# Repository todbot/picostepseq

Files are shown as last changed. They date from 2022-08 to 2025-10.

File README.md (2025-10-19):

# PicoStepSeq

PicoStepSeq is an 8-step MIDI sequencer using a Raspberry Pi Pico, an I2C SSD1306 OLED display, a rotary encoder. and 8 "Step Switches".  It outputs via USB MIDI and Serial MIDI via TRS-A 3.5mm.

It is designed as a potential DIY kit for people with beginner-level soldering skills
Part count is minimal, with all parts are through-hole, except for the two MIDI jacks,
which are easily solderable by hand.

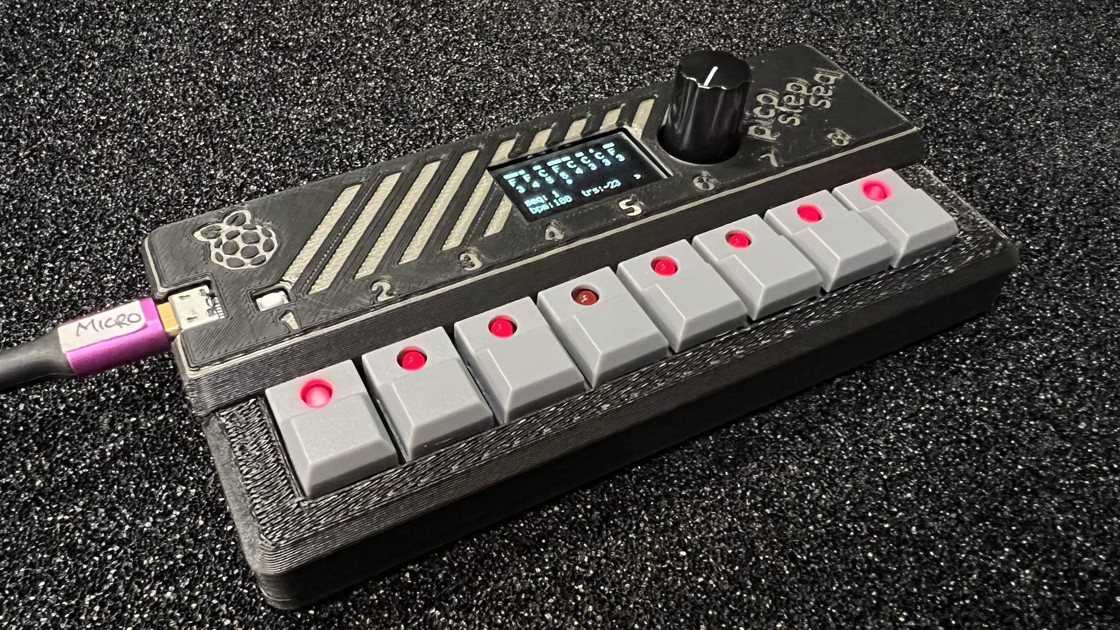
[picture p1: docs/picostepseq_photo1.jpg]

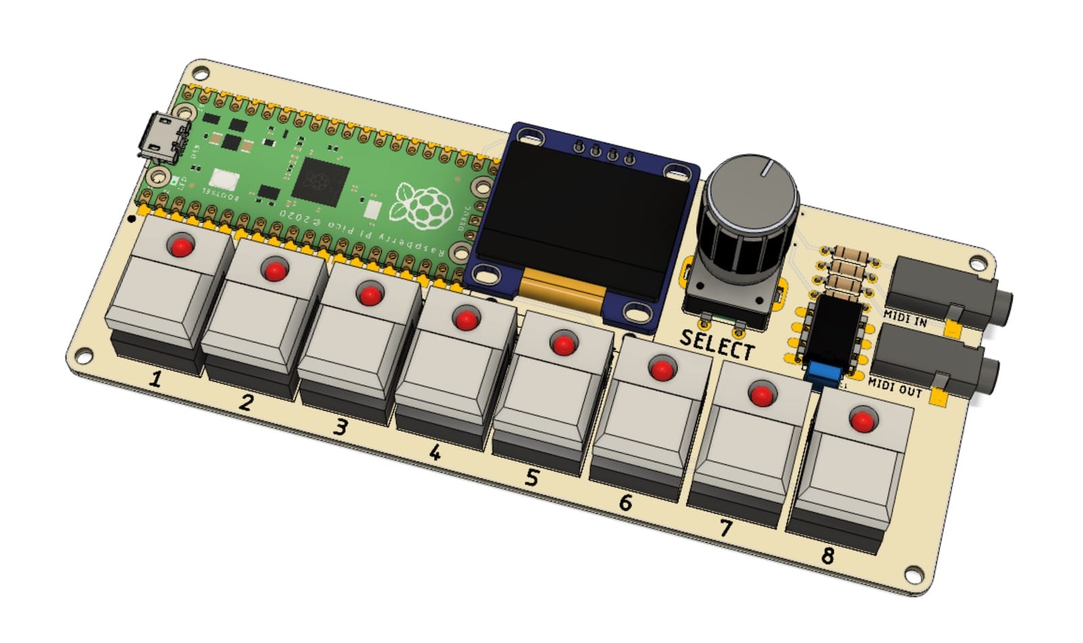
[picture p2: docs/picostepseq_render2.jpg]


## Demo videos

https://user-images.githubusercontent.com/274093/185005269-afb4c3f7-0ca1-40c8-a17d-6e4756943d87.mov

https://user-images.githubusercontent.com/274093/196536711-abd25514-53b9-4710-8ff6-1fa3559f0028.mp4

Also featured in [MagPi Magazine #123](https://magpi.raspberrypi.com/articles/picostepseq-rp2040-music-maker), and [in print too](https://magpi.raspberrypi.com/issues/123)!

## How to use

In use, PicoStepSeq has two states: Play and Pause.
It is designed so you never have to stop playing to edit and save/load a sequence.
It has 8 sequence slots that can be edited and are persistently saved to flash.

While Playing, the actions are:

- **Pause** -- Tap encoder button
- **Transpose sequence up/down** -- Turn encoder knob
- **Change tempo BPM** -- Push + turn encoder knob
- **Mute / Unmute steps** -- Tap corresponding step key
- **Change step's pitch** -- Hold step key, turn encoder knob
- **Change step's gate** -- Hold step key, push + turn encoder knob
- **Load sequence** -- Push encoder, tap step key 1-8, release encoder
- **Save sequence** -- Push encoder, hold step key 1-8 for 2 secs, release encoder

When Paused, the actions are:
- **Play** -- Tap encoder button
- **Play notes** -- tap corresponding step key to play its pitch
- **Change step's pitch** -- Hold step key, turn encoder knob

Sequence Save & Load:
- On startup, `saved_sequences.json` is read from disk and loaded into the 8 sequence slots
- Upon transitioning from Play to Pause, all 8 sequences will be written to disk as `saved_sequences.json`

### Step Keys

The 8 "step keys" have an LED that indicate current mute/unmute status and which step is currently being played.
Tap on a step key to mute/unmute it. Hold a key and turn the encoder knob to change the pitch of that step.

### Rotary Encoder

Turning the encoder adjusts the transpose amount of the playing sequence.  Push + turning adjusts the tempo.

### Display

PicoStepSeq can be used without really looking at the display (which is good because the display is very small).
The display is hopefully clear. It's divided into the top section showing 8 notes with gate info and the bottom section showing which sequence, current BPM & transpose, and if the sequencer is in play/pause mode.

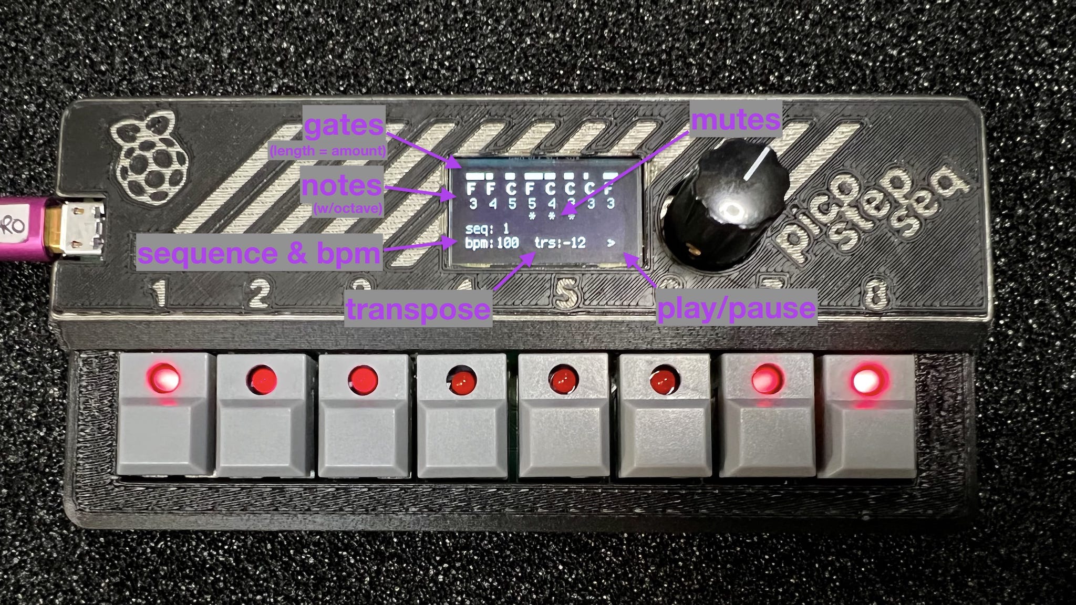
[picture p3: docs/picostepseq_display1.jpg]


### MIDI

PicoStepSeq outputs both USB MIDI and Serial MIDI.

There is preliminary support for syncing to MIDI Clock.

## Building

The schematic and PCB design is in the `hardware` directory.

An [OSHPark project](https://oshpark.com/shared_projects/vPWjBrmO) of the PCBs is ready to go.

[Build guide to come!]

### Enclosure

A 3d-printable enclosure is [available on Printables](https://www.printables.com/model/260860-picostepseq-midi-step-sequencer-w-raspberry-pi-pic)

The current enclosure is designed for the case where sockets are used for both the Pico and the OLED display.
This is so either can be removed for other uses, so you don't have to sacrifice a Pico if you want to try this out.

### Installing Firmware (CircuitPython)

#### Arduino version:

Probalby the easiest way to get PicoStepSeq running is to install the precompiled Arduino UF2
version in the [Releases](https://github.com/todbot/picostepseq/releases) section.

The Arduino firmware lives in `arduino/picostepseq`.
To compile the Arduino firmware, see the top of the `picostepseq.ino` file.

#### CircuitPython version:

To install the CircuitPython version:

The firmware lives in the `circuitpython/picostepseq` directory.

1. Copy all files in the `circuitpython/picostepseq` directory to the CIRCUITPY disk.

   If using a Mac terminal, you can do:
   ```sh
   cd picostepseq/circuitpython/picostepseq
   cp -rX * /Volumes/CIRCUITPY
   ```

2. Install the CircuitPython libraries `adafruit_displayio_ssd1306` and `adafruit_display_text`

   You can use the `circup` tool in Terminal for this:

   ```sh
   circup install adafruit_displayio_ssd1306 adafruit_display_text
   ```

   If you do not have `circup`, then you will need to copy the following files/dirs from the
   [Adafruit_CircuitPython_Bundle 8.x](https://circuitpython.org/libraries):
   ```
   adafruit_bitmap_font/
   adafruit_display_text/
   adafruit_displayio_ssd1306.mpy
   ```

3. Reset the board and the sequencer should come up!

   (The reset is important so that `boot.py` is run, which allows you to save sequences)

### Installing the Firmware (Arduino)

The Arduino version is a bit more tricky to get going. See the top of the `picostepseq.ino` file for details.

## Bill of Materials

Here is a [Digikey cart with most parts](https://www.digikey.com/short/8qh7p87z).

Links also included below for major parts

For basic USB MIDI functionality:

- 1 - "picostepseq" PCB ([OSHpark](https://oshpark.com/shared_projects/vPWjBrmO), also see "hardware" directory for gerbers)
- 1 - Raspberry Pi Pico ([Adafruit](https://www.adafruit.com/product/4864), [Digikey](https://www.digikey.com/en/products/detail/raspberry-pi/SC0915/13624793))
- 1 - 0.96" I2C OLED SSD1306 128x64 display ([Amazon](https://amzn.to/3K1ZAoo))
  - w/ pins in order GND, VCC, SCL, SDA; some have GND & VCC swapped
- 1 - EC11 style rotary encoder w/ switch ([Digikey](https://www.digikey.com/en/products/detail/bourns-inc/PEC11R-4215F-S0024/4499665), [Adafruit](https://www.adafruit.com/product/377)]
- 8 - "step switch" w/ built-in LED ([Adafruit](https://www.adafruit.com/product/5519)]
- 8 - resistor 1k (R1-R8, 500 ohm also works) ([Digikey](https://www.digikey.com/en/products/detail/stackpole-electronics-inc/CF18JT1K00/1741612), [Adafruit](https://www.adafruit.com/product/4294)]
- 1 - encoder knob ("Davies 1900" style works well, [Adafruit](https://www.adafruit.com/product/5541))

For both USB + Serial MIDI, add:

- 2 - 3.5mm TRS jack, SJ-3523-SMT-TR (J1,J2)
([Digikey](https://www.digikey.com/en/products/detail/cui-devices/SJ-3523-SMT-TR/281297))
- 1 - 6N138 optoisolator (U2) ([Digikey](https://www.digikey.com/en/products/detail/liteon/6N138/1969179))
- 1 - 100n capacitor (C1) ([Digikey](https://www.digikey.com/en/products/detail/vishay-beyschlag-draloric-bc-components/K104K15X7RF5TL2/286538), [Adafruit](https://www.adafruit.com/product/753))
- 1 - resistor 10 ohm (R1)
- 1 - resistor 30 ohm (R2) (47 ohm also works)
- 1 - resistor 220 ohm (R3)
- 1 - resistor 4.7k ohm (R4)

And if you've not used ["TRS MIDI"](https://minimidi.world/#types) and have normal 5-pin DIN MIDI jacks
on your gear, you'll need a few:
- Type A" MIDI adapter ([PerfectCircuit](https://www.perfectcircuit.com/make-noise-0-coast-midi-cable.html) or [Amazon](https://amzn.to/3Tb6DiU))

You can attach the Pico & the OLED display how you like, but if using the 3d-printable "picostepseq_headers" case, you will also need:

- 2 - 20-pin header socket ([Digikey](https://www.digikey.com/en/products/detail/sullins-connector-solutions/PPPC201LFBN-RC/810192), [Adafruit](https://www.adafruit.com/product/5583))
- 2 - 20-pin header pins ([Digikey](https://www.digikey.com/en/products/detail/adam-tech/PH1-20-UA/9830398), [Adafruit ](https://www.adafruit.com/product/392))
- 1 - 4-pin female (same as above, break off 4-pin chunk)

## Firmware Design (CircuitPython)

Timing in CircuitPython is all over the place and there's no periodic timer support (like `Timer` in MicroPython).
So, in order to minimize timing jitter due to I2C `displayio` transactions, the UI & display update code
is designed so only the minimal amount of information is changed on the display in one iteration of the main
UI loop. This is most noticable when loading a new sequence: the entire sequence is revealed only after a full
loop.

The sequencer "beat scheduler" also tries to account for the variation in CircuitPython timing by
measuring an "error" on the delta_t between beats and applies that to the next beat

[More to come!]

Thanks to [Winterbloom](https://github.com/wntrblm) and [@theacodes](https://github.com/theacodes) for the awesome
[SmolMIDI library](https://github.com/wntrblm/Winterbloom_SmolMIDI) for efficient MIDI parsing.
(and for [really cool Eurorack synthesizer devices](https://winterbloom.com/shop))

**Note:** If you have an [Adafruit MacroPad RP2040](https://www.adafruit.com/product/5128),
you can experiment with the sequencer without building any hardware! The code will auto-detect
if it's running on a MacroPad. Rotate the MacroPad so the display is on the left,
then the sequencer keys are arranged as two rows of four.

Here's a demo video of an early dev version of the sequencer running on the MacroPad:

https://user-images.githubusercontent.com/274093/196534059-c9460560-1983-42a2-818f-853e90acd9bf.mp4

## PCB layout

This is the original version that has a typo on the MIDI jacks.

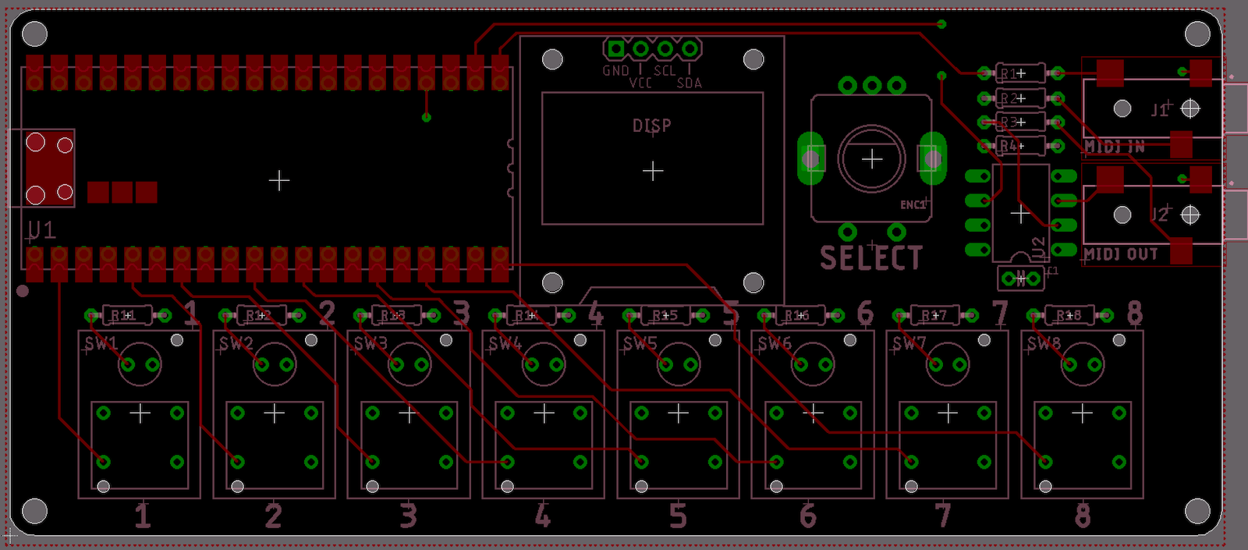
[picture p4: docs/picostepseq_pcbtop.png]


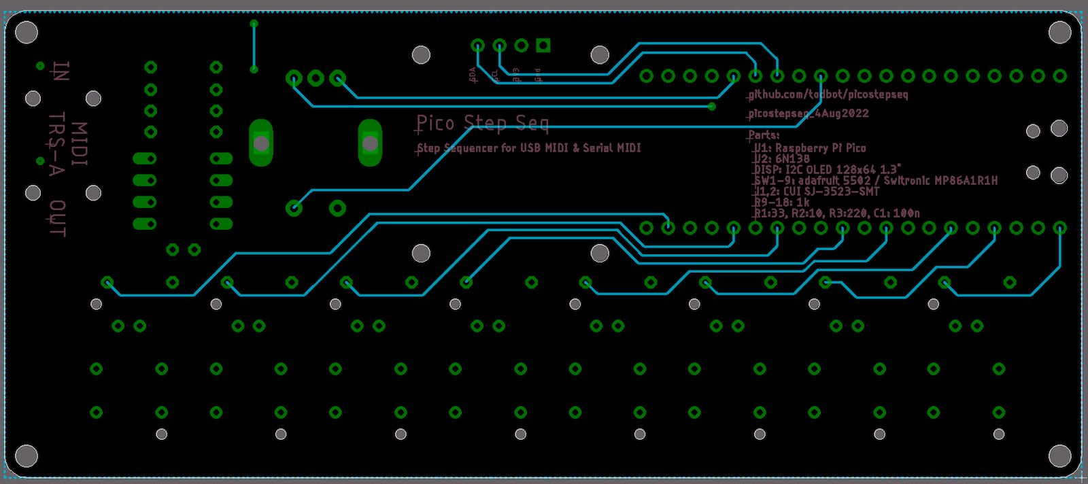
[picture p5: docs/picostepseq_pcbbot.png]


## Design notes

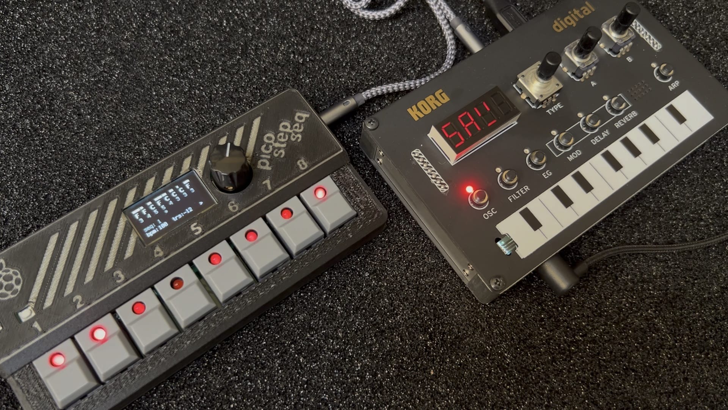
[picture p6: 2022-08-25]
docs/picostepseq_korg1.jpg

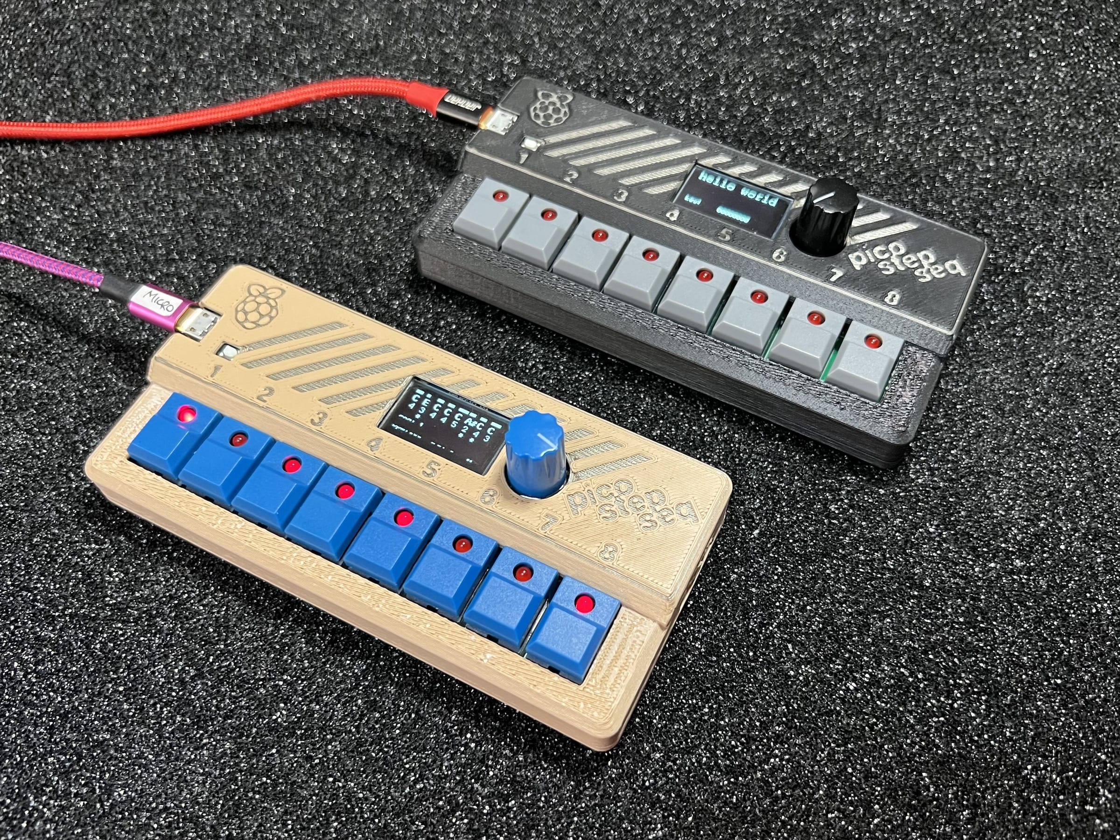
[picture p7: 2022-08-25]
docs/picostepseq_multicolor.jpg

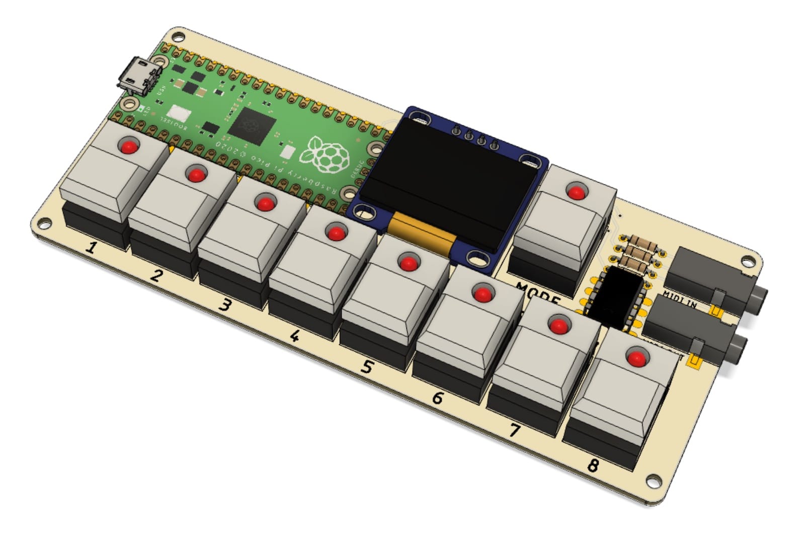
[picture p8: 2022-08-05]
docs/picostepseq_render1.jpg

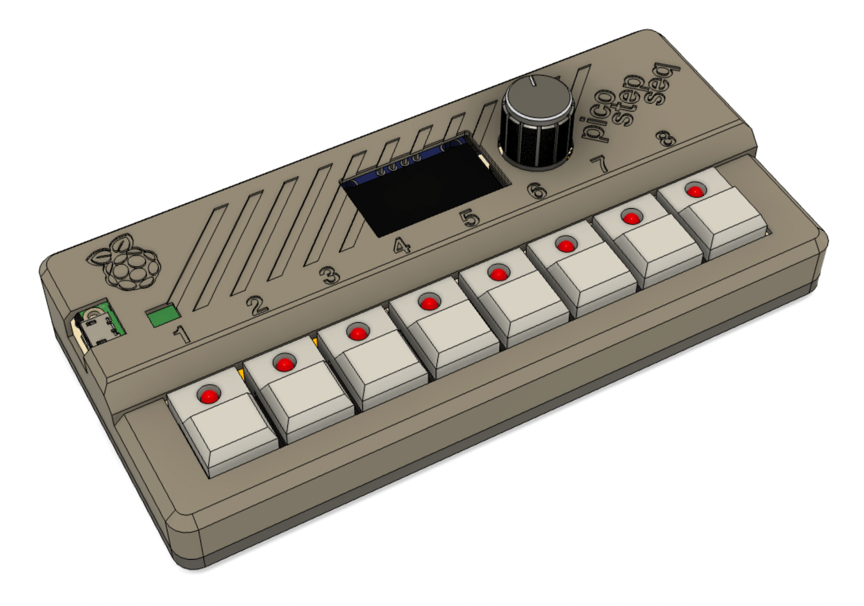
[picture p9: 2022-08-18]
case/picostepseq_case_render1.png

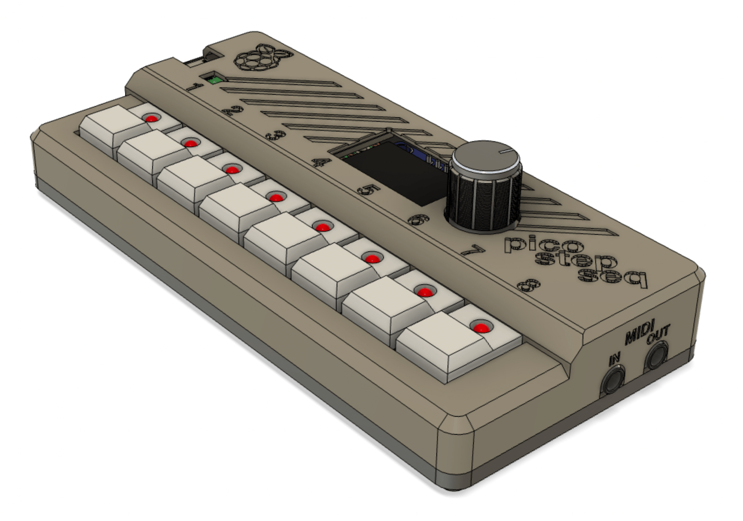
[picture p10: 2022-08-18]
case/picostepseq_case_render2.png

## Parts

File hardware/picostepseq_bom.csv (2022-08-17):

Qty | Value | Device | Package | Parts | Description | CUI_PURCHASE_URL | DESCRIPTION | DIGI-KEY_PART_NUMBER | MF | MP | MPN | OC_FARNELL | OC_NEWARK | PACKAGE | POPULARITY | PURCHASE-URL | SPICEPREFIX
1 |  | C-EU025-025X050 | C025-025X050 | C1 | CAPACITOR, European symbol |  |  |  |  |  |  |  |  |  | 65 |  | C
1 |  | RASPBERRY_PICO-NO_DEBUG | PICO-PKG-NO_DEBUG | U1
1 | 10 | R-EU_0204/7 | 0204/7 | R1 | RESISTOR, European symbol |  |  |  |  |  |  |  |  |  | 79 |  | R
8 | 1k | R-EU_0204/7 | 0204/7 | R11, R12, R13, R14, R15, R16, R17, R18 | RESISTOR, European symbol |  |  |  |  |  |  |  |  |  | 79 |  | R
1 | 220 | R-EU_0204/7 | 0204/7 | R3 | RESISTOR, European symbol |  |  |  |  |  |  |  |  |  | 79 |  | R
1 | 33 | R-EU_0204/7 | 0204/7 | R2 | RESISTOR, European symbol |  |  |  |  |  |  |  |  |  | 79 |  | R
1 | 4.70k | R-EU_0204/7 | 0204/7 | R4 | RESISTOR, European symbol |  |  |  |  |  |  |  |  |  | 79 |  | R
1 | 6N137 | 6N137 | DIL08 | U2 | MOTOROLA OPTO COUPLER |  |  |  |  |  | 6N137 | 1328376 | 52M1895 |  | 2
1 | DISPLAY-OLED-128X64-I2C | DISPLAY-OLED-128X64-I2C | DISPLAY-OLED-128X64-I2C | DISP | 128x64 Dot Matrix OLED Module based on SSD1306 chip
8 | LED_SWITCHSTEP | LED_SWITCHSTEP | LED_SWITCH_STEP | SW1, SW2, SW3, SW4, SW5, SW6, SW7, SW8 | Step switch with LED, like on old drum machines
1 | PEC11 | ENCODER_PLUS_SWITCH_BOURNS_PEC11 | PEC11+SWITCH | ENC1 | Rotary Encoder with Built-In Switch
2 | SJ-3523-SMT | SJ-3523-SMT | CUI_SJ-3523-SMT | J1, J2 | Audio Jack Connector 3.5 mm Low Profile Surface Mount Stereo Jack, 3 Pin Right-Angle | https://www.cuidevices.com/product/interconnect/connectors/audio-connectors/jacks/sj-352x-smt-series | 3.5 mm, Stereo, Right Angle, Surface Mount (SMT), 3 Conductors, 0~1 Internal Switches, Audio Jack Connector | CP-3523SJCT-ND | CUI Devices | SJ-3523-SMT-TR |  |  |  | None |  | https://pricing.snapeda.com/search/part/SJ-3523-SMT-TR/?ref=eda

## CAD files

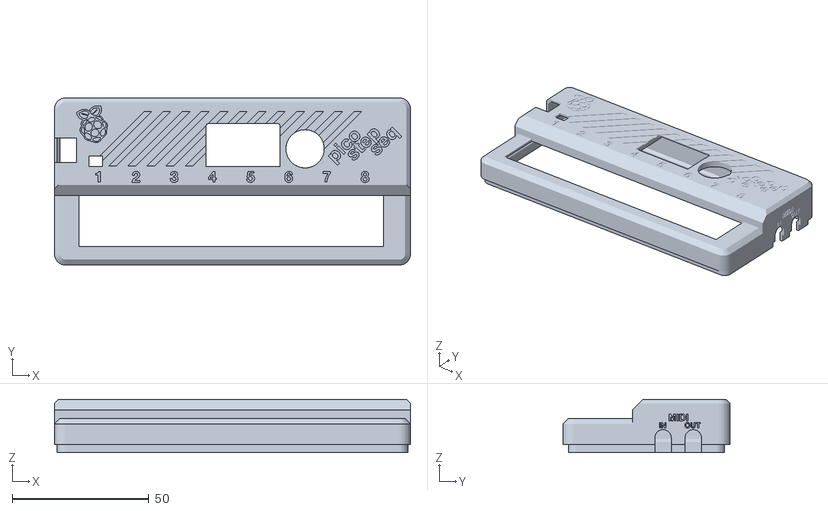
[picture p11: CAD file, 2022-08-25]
case/picostepseq_case_top.stl
130.3 x 61.2 x 19.6

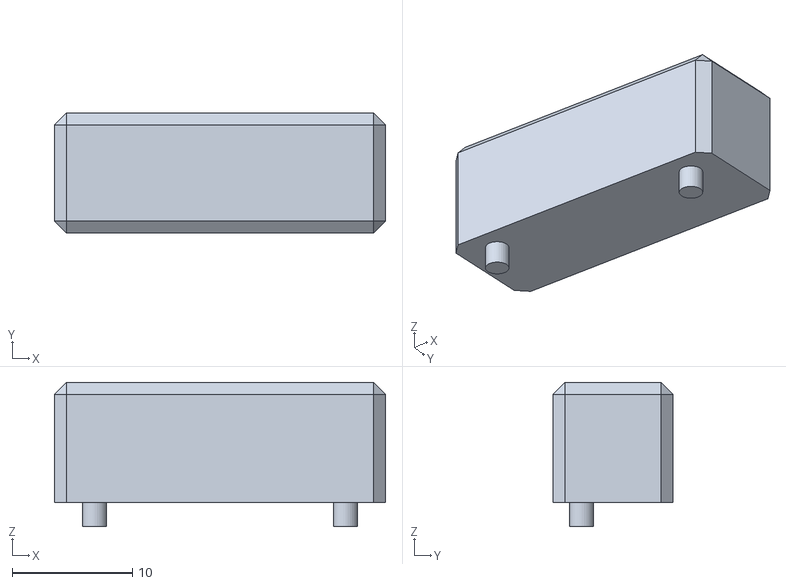
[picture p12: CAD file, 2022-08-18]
case/picostepseq_case_oledspacer.stl
27.5 x 10.0 x 12.0

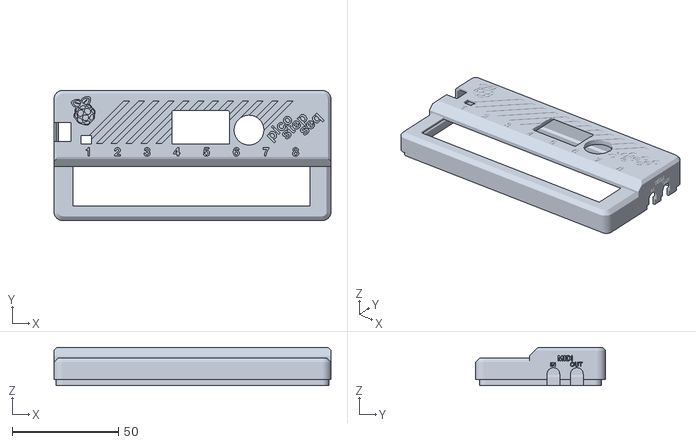
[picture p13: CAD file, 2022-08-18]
case/picostepseq_case_top_short.stl
130.3 x 61.2 x 18.1

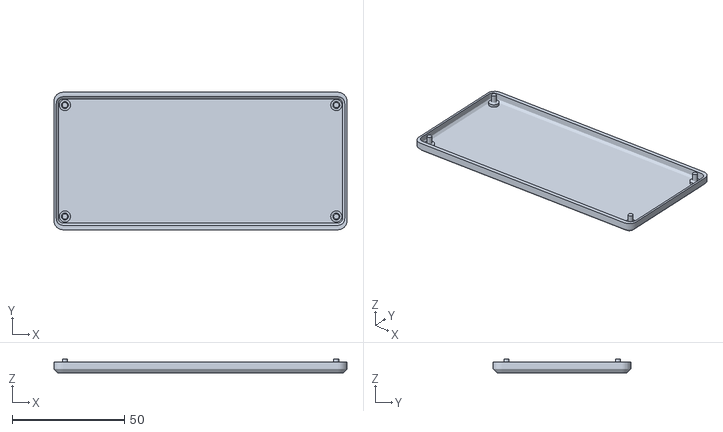
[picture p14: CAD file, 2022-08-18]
case/picostepseq_case_bottom.stl
130.3 x 61.2 x 6.30

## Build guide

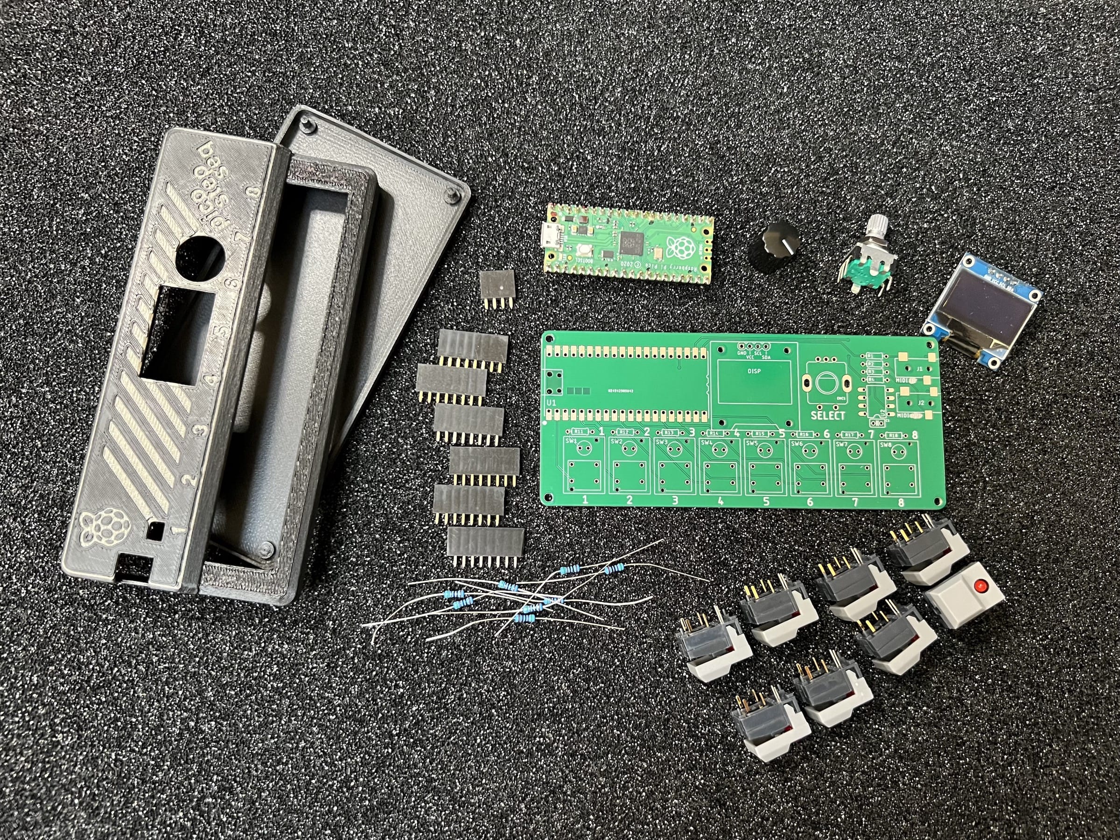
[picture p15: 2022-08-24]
docs/picostepseq_assembly1.jpg

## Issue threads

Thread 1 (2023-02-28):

Circuit Python libraries needed

gmeader, 2023-02-28:
I got my board assembled and it works.
The following Circuit Python Libraries are needed in the lib folder to successfully run both the test/hardware_test_code.py and the main picostepseq/code.py:

- adafruit_bitmap_font
- adafruit_display_text
- adafruit_debouncer.mpy
- adafruit_displayio_ssd1306,mpy
- adafruit_ticks.mpy

todbot, 2023-04-22:
Thanks, @gmeader, and sorry about that!  I'm so used to `circup` I forget not everyone uses it.  Fixes soon.

Closed 2023-04-22.

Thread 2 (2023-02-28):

Error while trying to save - Read-only filesystem

gmeader, 2023-02-28:
When I finish a sequence, it displays:

WRITING ALL SEQUENCES
Traceback (most recent call last):
  File "code.py", line 269, in <module>
  File "code.py", line 153, in sequences_write
OSError: [Errno 30] Read-only filesystem
]0;🐍153@code.py OSError | 8.0.3\

I do have the boot.py file there (that is supposed to be making the filesystem writable)

Oh, I have to reboot the board so that it will execute the boot.py
Now it works properly - so this issue is moot.

Closed 2023-04-22.

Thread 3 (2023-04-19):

External or internal sync

condor13, 2023-04-19:
Hey, I built this "bad boy" so I can sequence my other build [Beatsqueezer](https://www.hypnotriod.org/beatsqueezer/) via midi.
Is there any way I could add a external clock in or external clock out? (volca style) I built some other Arduino noise boxes and want to sync them. Not very familiar with python, if you could point me in the right direction..
Thanks :)

condor13, 2023-04-19:
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

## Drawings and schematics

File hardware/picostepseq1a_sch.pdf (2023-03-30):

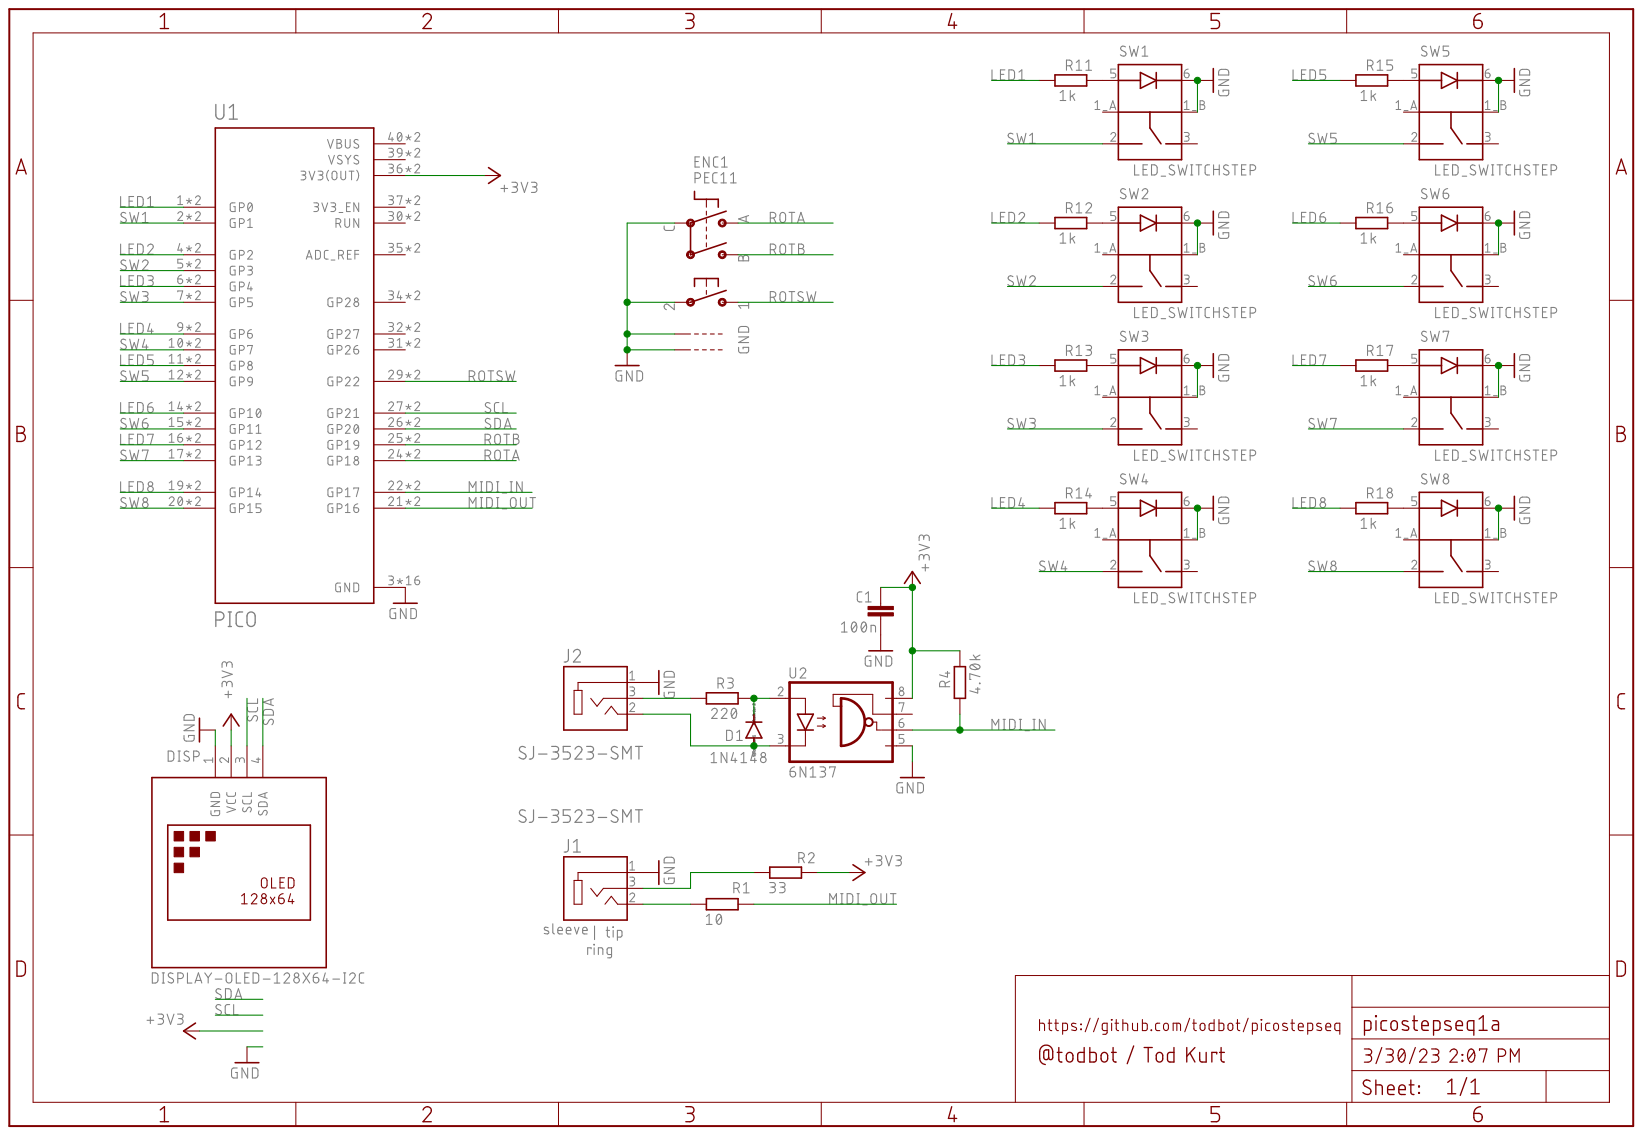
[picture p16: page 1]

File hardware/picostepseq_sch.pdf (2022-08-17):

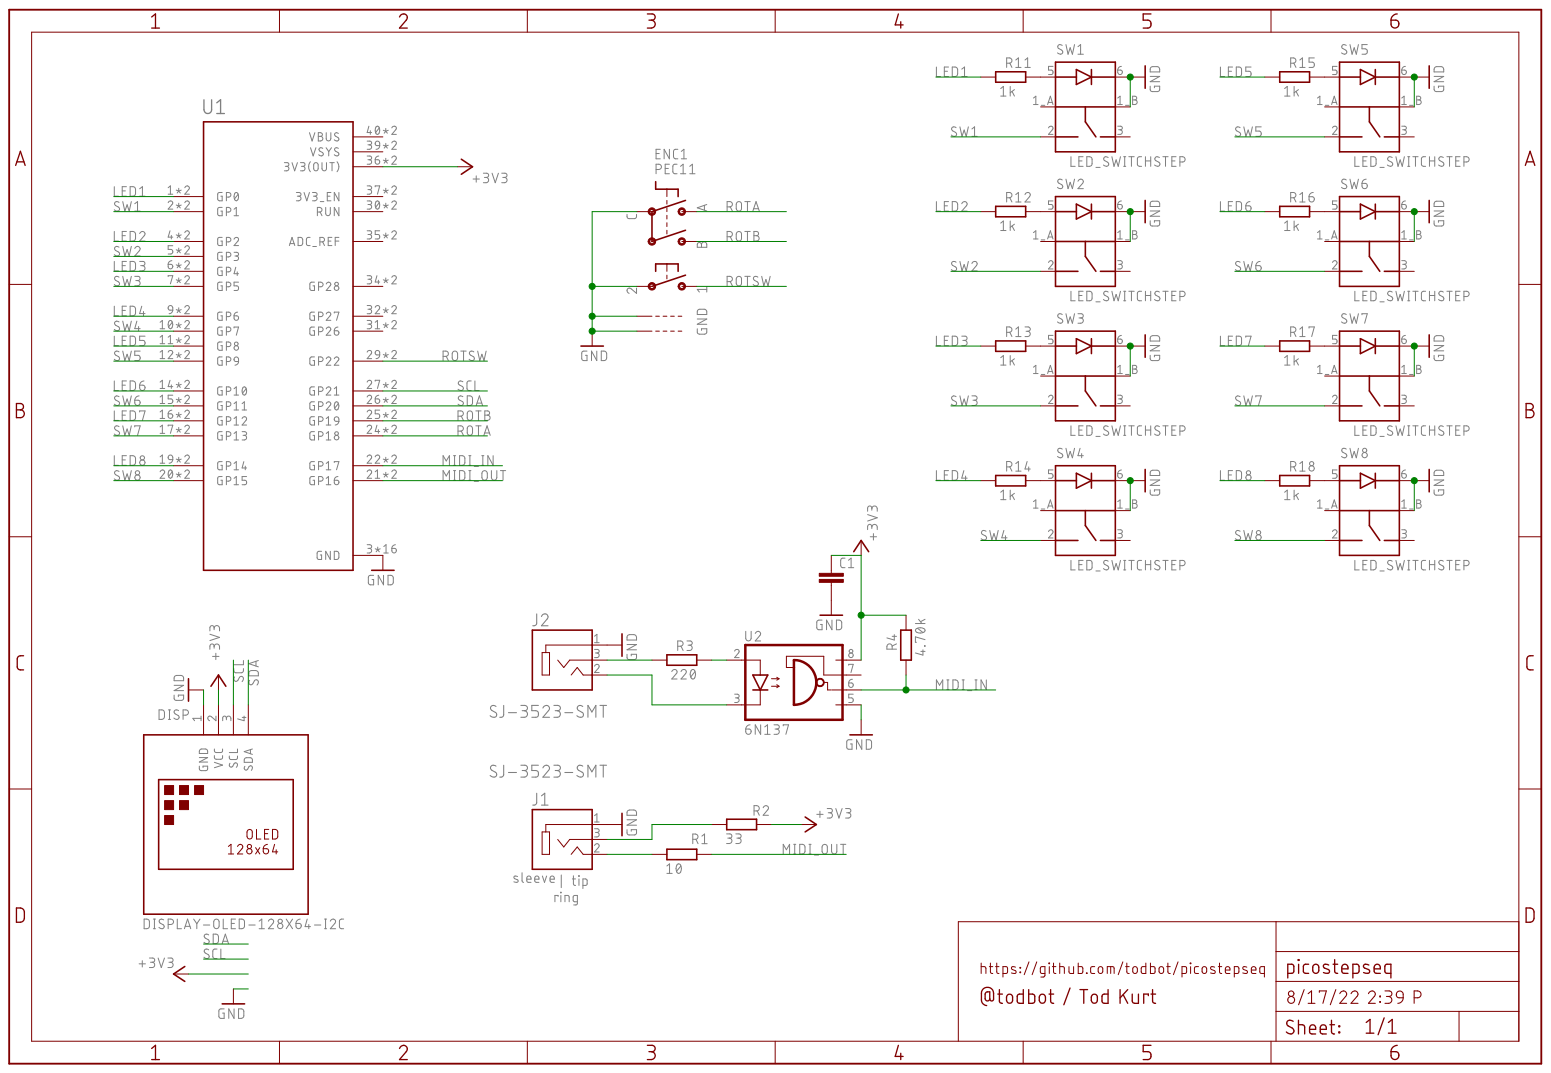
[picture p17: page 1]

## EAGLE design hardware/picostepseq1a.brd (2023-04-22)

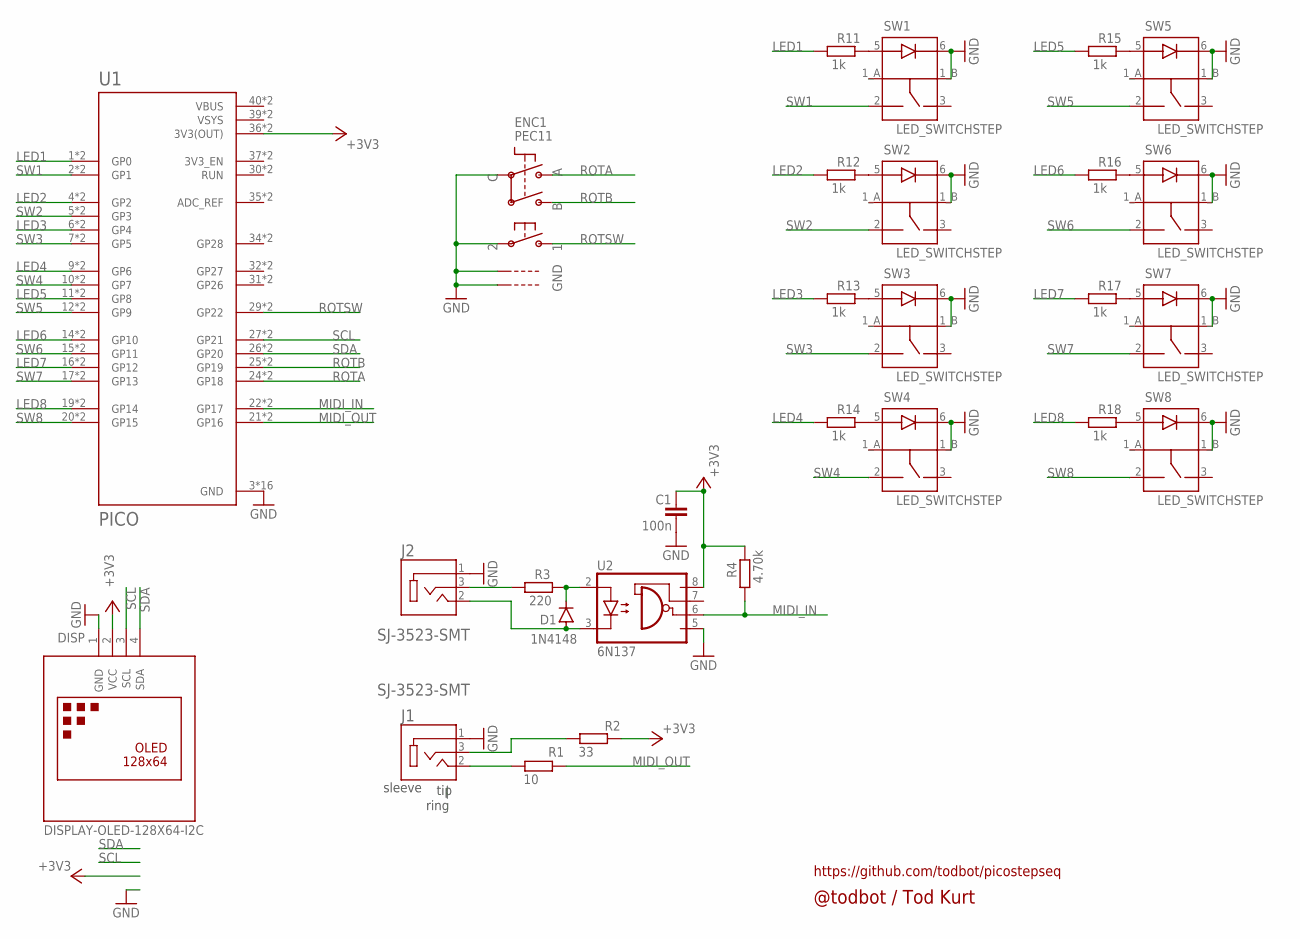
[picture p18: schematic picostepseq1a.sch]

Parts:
C1: 100n; C025-025X050
D1: 1N4148; DO35-7
DISP: DISPLAY-OLED-128X64-I2C
ENC1: PEC11; PEC11+SWITCH
J1, J2: SJ-3523-SMT; CUI_SJ-3523-SMT
R1: 10; 0204/7
R2: 33; 0204/7
R3: 220; 0204/7
R4: 4.70k; 0204/7
R11, R12, R13, R14, R15, R16, R17, R18: 1k; 0204/7
SW1, SW2, SW3, SW4, SW5, SW6, SW7, SW8: LED_SWITCHSTEP; LED_SWITCH_STEP
U1: PICO; PICO-PKG-NO_DEBUG
U2: 6N137; DIL08

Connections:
+3V3: C1.1, DISP.2 (VCC), R2.2, R4.1, U1.36 (3V3(OUT)), U1.P$36 (3V3(OUT)), U2.8 (VCC)
GND: C1.2, DISP.1 (GND), ENC1.P$2, ENC1.P$C, ENC1.P$GND1, ENC1.P$GND2, J1.1, J2.1, SW1.1_B, SW1.6, SW2.1_B, SW2.6, SW3.1_B, SW3.6, SW4.1_B, SW4.6, SW5.1_B, SW5.6, SW6.1_B, SW6.6, SW7.1_B, SW7.6, SW8.1_B, SW8.6, U1.3 (GND), U1.8 (GND), U1.13 (GND), U1.18 (GND), U1.23 (GND), U1.28 (GND), U1.33 (GND), U1.38 (GND), U1.P$3 (GND), U1.P$8 (GND), U1.P$13 (GND), U1.P$18 (GND), U1.P$23 (GND), U1.P$28 (GND), U1.P$33 (GND), U1.P$38 (GND), U2.5 (GND)
LED1: R11.2, U1.1 (GP0), U1.P$1 (GP0)
LED2: R12.2, U1.4 (GP2), U1.P$4 (GP2)
LED3: R13.2, U1.6 (GP4), U1.P$6 (GP4)
LED4: R14.2, U1.9 (GP6), U1.P$9 (GP6)
LED5: R15.2, U1.11 (GP8), U1.P$11 (GP8)
LED6: R16.2, U1.14 (GP10), U1.P$14 (GP10)
LED7: R17.2, U1.16 (GP12), U1.P$16 (GP12)
LED8: R18.2, U1.19 (GP14), U1.P$19 (GP14)
MIDI_IN: R4.2, U1.22 (GP17), U1.P$22 (GP17), U2.6 (VO)
MIDI_OUT: R1.2, U1.21 (GP16), U1.P$21 (GP16)
unnamed: J1.2, R1.1
unnamed: D1.C, R3.1, U2.2 (A)
unnamed: D1.A, J2.2, U2.3 (C)
unnamed: R11.1, SW1.5
unnamed: R12.1, SW2.5
unnamed: R13.1, SW3.5
unnamed: R14.1, SW4.5
unnamed: R15.1, SW5.5
unnamed: R16.1, SW6.5
unnamed: R17.1, SW7.5
unnamed: R18.1, SW8.5
unnamed: J1.3, R2.1
unnamed: J2.3, R3.2
ROTA: ENC1.P$A, U1.24 (GP18), U1.P$24 (GP18)
ROTB: ENC1.P$B, U1.25 (GP19), U1.P$25 (GP19)
ROTSW: ENC1.P$1, U1.29 (GP22), U1.P$29 (GP22)
SCL: DISP.3 (SCL), U1.27 (GP21), U1.P$27 (GP21)
SDA: DISP.4 (SDA), U1.26 (GP20), U1.P$26 (GP20)
SW1: SW1.2, U1.2 (GP1), U1.P$2 (GP1)
SW2: SW2.2, U1.5 (GP3), U1.P$5 (GP3)
SW3: SW3.2, U1.7 (GP5), U1.P$7 (GP5)
SW4: SW4.2, U1.10 (GP7), U1.P$10 (GP7)
SW5: SW5.2, U1.12 (GP9), U1.P$12 (GP9)
SW6: SW6.2, U1.15 (GP11), U1.P$15 (GP11)
SW7: SW7.2, U1.17 (GP13), U1.P$17 (GP13)
SW8: SW8.2, U1.20 (GP15), U1.P$20 (GP15)
VBUS: U1.40 (VBUS), U1.P$40 (VBUS)
VSYS: U1.39 (VSYS), U1.P$39 (VSYS)

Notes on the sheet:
tip
| ring
sleeve
@todbot / Tod Kurt
https://github.com/todbot/picostepseq

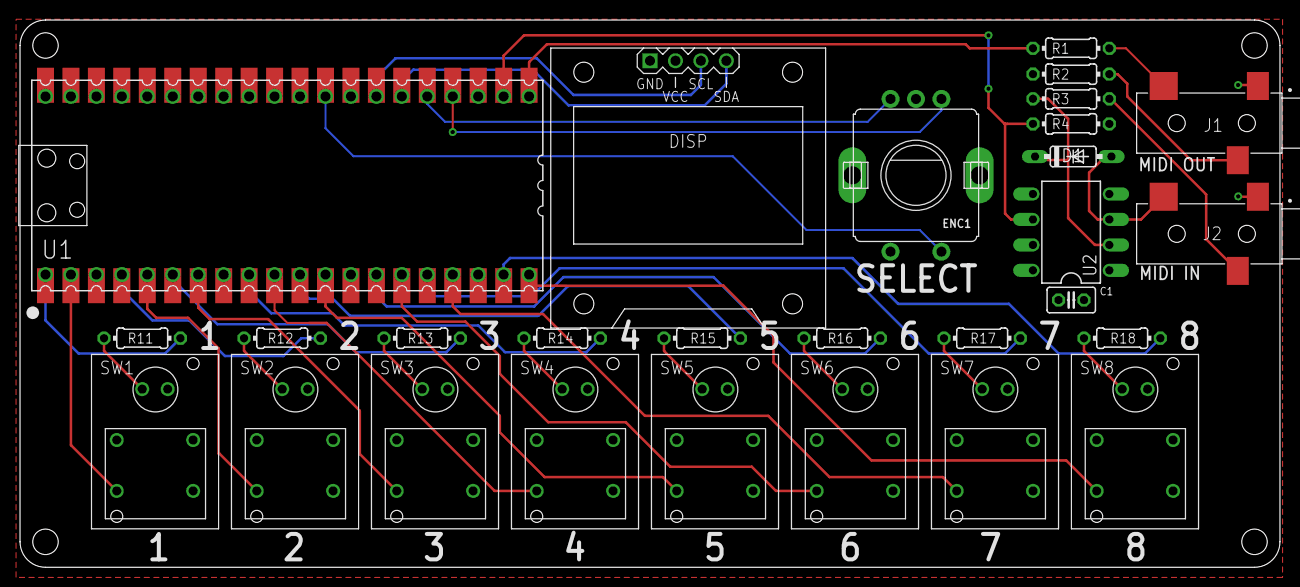
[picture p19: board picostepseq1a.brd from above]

Board: 2 copper layers, 125.7 x 54.6 mm, 28 parts (0 on the bottom side), 40 nets.

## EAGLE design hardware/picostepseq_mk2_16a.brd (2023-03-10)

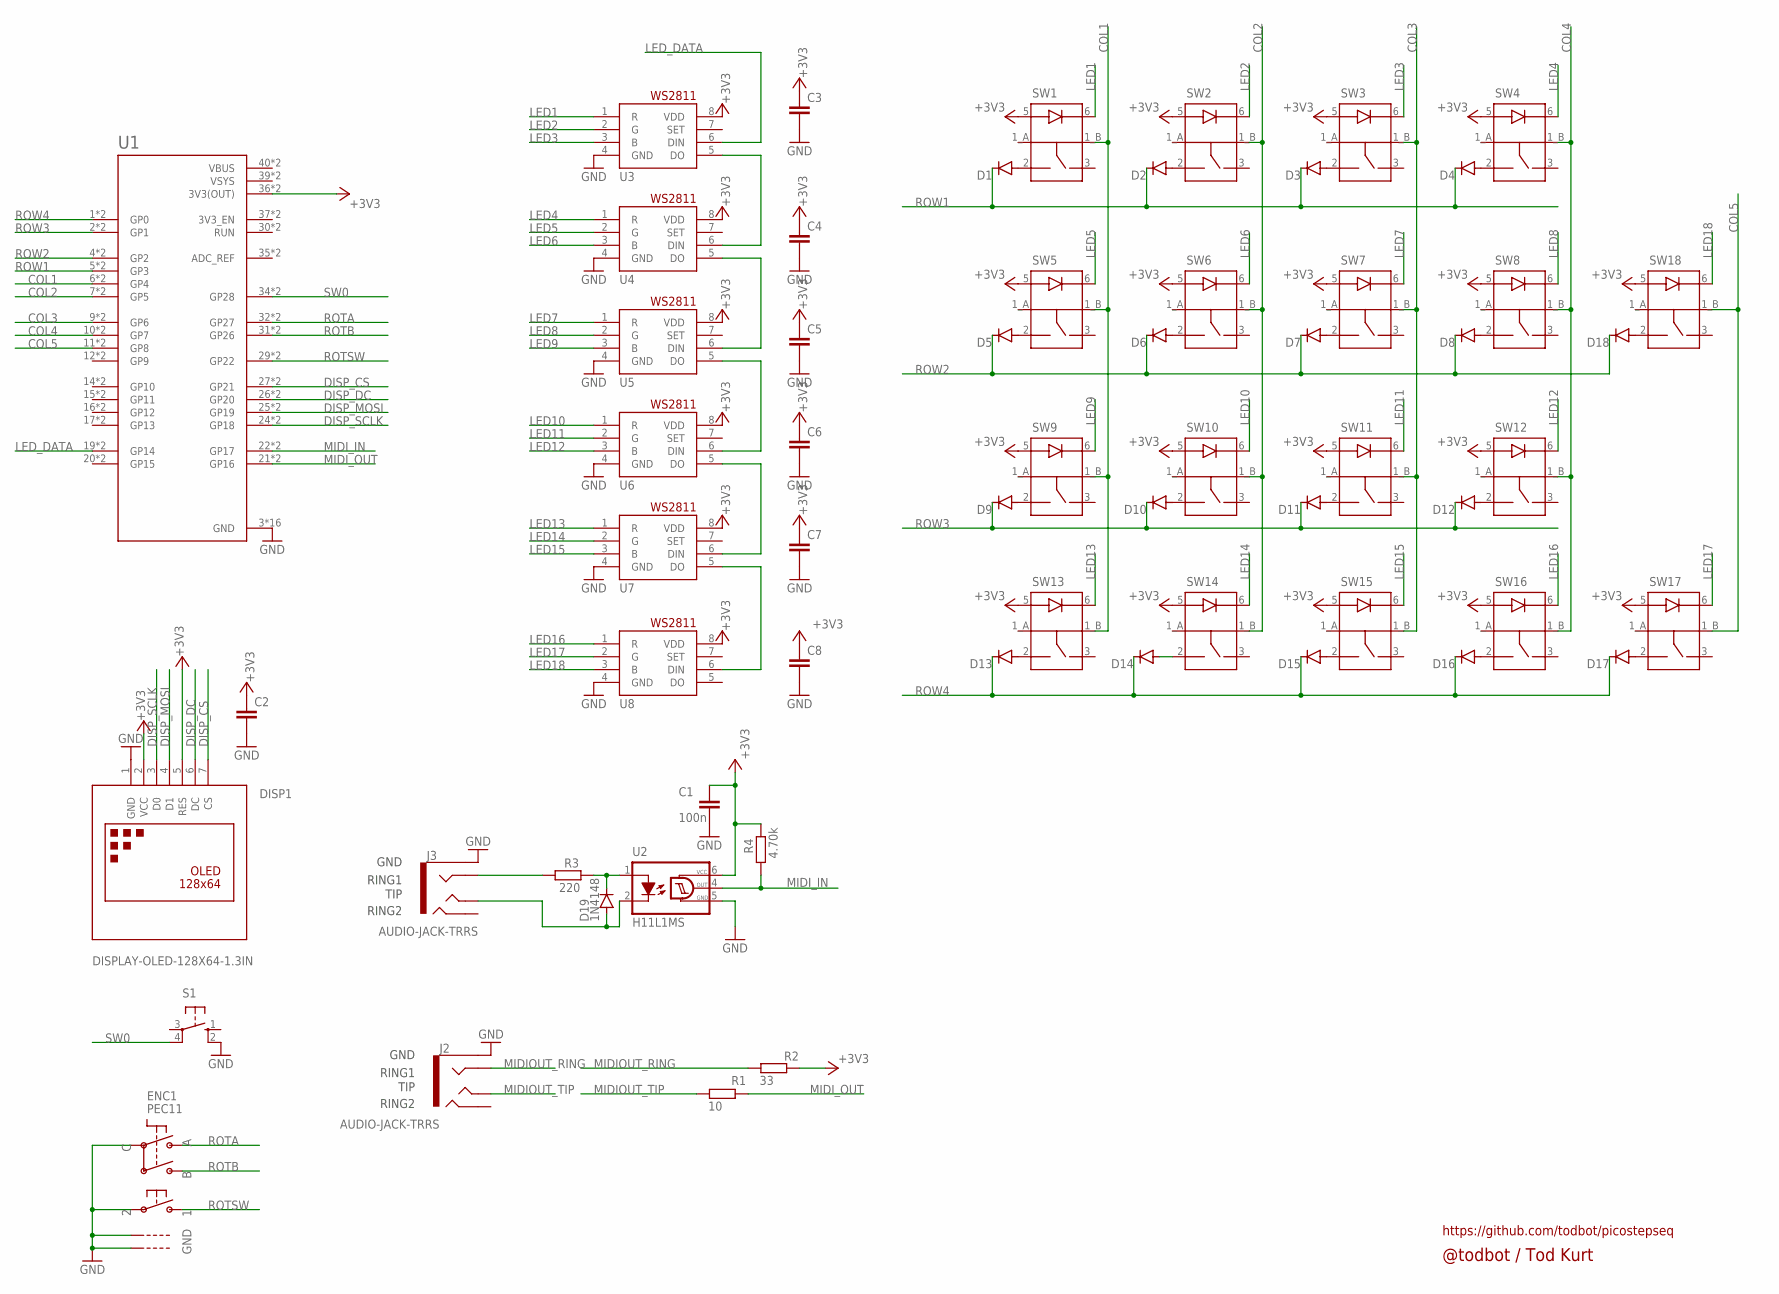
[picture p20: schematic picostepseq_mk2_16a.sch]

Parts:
C1: 100n; C0805
C2, C3, C4, C5, C6, C7, C8: C-EUC0805; C0805
D1, D2, D3, D4, D5, D6, D7, D8, D9, D10, D11, D12, D13, D14, D15, D16, D17, D18: DIODE-SOD123; SOD123
D19: 1N4148; SOD123
DISP1: DISPLAY-OLED-128X64-1.3IN
ENC1: PEC11; PEC11+SWITCH
J2, J3: AUDIO-JACK-TRRS; PJ-320D_SPARKFUN
R1: 10; R0805
R2: 33; R0805
R3: 220; R0805
R4: 4.70k; R0805
S1: 10-XX; B3F-10XX
SW1, SW2, SW3, SW4, SW5, SW6, SW7, SW8, SW9, SW10, SW11, SW12, SW13, SW14, SW15, SW16, SW17, SW18: LED_SWITCHSTEP; LED_SWITCH_STEP
U1: RASPBERRY_PICO-NO_DEBUG; PICO-PKG-NO_DEBUG
U2: H11L1MS; DIL6-SMD; MPN2 H11L1S; LCSC C78589
U3, U4, U5, U6, U7, U8: WS2811-SOP8; SO08-SKINNYPADS

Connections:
+3V3: C1.1, C2.1, C3.1, C4.1, C5.1, C6.1, C7.1, C8.1, DISP1.2 (VCC), DISP1.5 (RES), R2.2, R4.1, SW1.5, SW2.5, SW3.5, SW4.5, SW5.5, SW6.5, SW7.5, SW8.5, SW9.5, SW10.5, SW11.5, SW12.5, SW13.5, SW14.5, SW15.5, SW16.5, SW17.5, SW18.5, U1.36 (3V3(OUT)), U1.P$36 (3V3(OUT)), U2.6 (VCC), U3.8 (VDD), U4.8 (VDD), U5.8 (VDD), U6.8 (VDD), U7.8 (VDD), U8.8 (VDD)
COL1: SW1.1_B, SW5.1_B, SW9.1_B, SW13.1_B, U1.6 (GP4), U1.P$6 (GP4)
COL2: SW2.1_B, SW6.1_B, SW10.1_B, SW14.1_B, U1.7 (GP5), U1.P$7 (GP5)
COL3: SW3.1_B, SW7.1_B, SW11.1_B, SW15.1_B, U1.9 (GP6), U1.P$9 (GP6)
COL4: SW4.1_B, SW8.1_B, SW12.1_B, SW16.1_B, U1.10 (GP7), U1.P$10 (GP7)
COL5: SW17.1_B, SW18.1_B, U1.11 (GP8), U1.P$11 (GP8)
DISP_CS: DISP1.7 (CS), U1.27 (GP21), U1.P$27 (GP21)
DISP_DC: DISP1.6 (DC), U1.26 (GP20), U1.P$26 (GP20)
DISP_MOSI: DISP1.4 (D1), U1.25 (GP19), U1.P$25 (GP19)
DISP_SCLK: DISP1.3 (D0), U1.24 (GP18), U1.P$24 (GP18)
GND: C1.2, C2.2, C3.2, C4.2, C5.2, C6.2, C7.2, C8.2, DISP1.1 (GND), ENC1.P$2, ENC1.P$C, ENC1.P$GND1, ENC1.P$GND2, J2.EARTH, J3.EARTH, S1.2 (S1), U1.3 (GND), U1.8 (GND), U1.13 (GND), U1.18 (GND), U1.23 (GND), U1.28 (GND), U1.33 (GND), U1.38 (GND), U1.P$3 (GND), U1.P$8 (GND), U1.P$13 (GND), U1.P$18 (GND), U1.P$23 (GND), U1.P$28 (GND), U1.P$33 (GND), U1.P$38 (GND), U2.5 (GND), U3.4 (GND), U4.4 (GND), U5.4 (GND), U6.4 (GND), U7.4 (GND), U8.4 (GND)
LED1: SW1.6, U3.1 (R)
LED2: SW2.6, U3.2 (G)
LED3: SW3.6, U3.3 (B)
LED4: SW4.6, U4.1 (R)
LED5: SW5.6, U4.2 (G)
LED6: SW6.6, U4.3 (B)
LED7: SW7.6, U5.1 (R)
LED8: SW8.6, U5.2 (G)
LED9: SW9.6, U5.3 (B)
LED10: SW10.6, U6.1 (R)
LED11: SW11.6, U6.2 (G)
LED12: SW12.6, U6.3 (B)
LED13: SW13.6, U7.1 (R)
LED14: SW14.6, U7.2 (G)
LED15: SW15.6, U7.3 (B)
LED16: SW16.6, U8.1 (R)
LED17: SW17.6, U8.2 (G)
LED18: SW18.6, U8.3 (B)
LED_DATA: U1.19 (GP14), U1.P$19 (GP14), U3.6 (DIN)
MIDIOUT_RING: J2.RING1, R2.1
MIDIOUT_TIP: J2.TIP, R1.1
MIDI_IN: R4.2, U1.22 (GP17), U1.P$22 (GP17), U2.4 (OUT)
MIDI_OUT: R1.2, U1.21 (GP16), U1.P$21 (GP16)
unnamed: D18.A, SW18.2
unnamed: D17.A, SW17.2
unnamed: D1.A, SW1.2
unnamed: D2.A, SW2.2
unnamed: D3.A, SW3.2
unnamed: D4.A, SW4.2
unnamed: D5.A, SW5.2
unnamed: D9.A, SW9.2
unnamed: D10.A, SW10.2
unnamed: D11.A, SW11.2
unnamed: D12.A, SW12.2
unnamed: D13.A, SW13.2
unnamed: D14.A, SW14.2
unnamed: D15.A, SW15.2
unnamed: D16.A, SW16.2
unnamed: D6.A, SW6.2
unnamed: U3.5 (DO), U4.6 (DIN)
unnamed: U4.5 (DO), U5.6 (DIN)
unnamed: D7.A, SW7.2
unnamed: U5.5 (DO), U6.6 (DIN)
unnamed: U6.5 (DO), U7.6 (DIN)
unnamed: U7.5 (DO), U8.6 (DIN)
unnamed: D8.A, SW8.2
unnamed: D19.C, R3.1, U2.1 (A)
unnamed: D19.A, J3.TIP, U2.2 (C)
unnamed: J3.RING1, R3.2
ROTA: ENC1.P$A, U1.32 (GP27), U1.P$32 (GP27)
ROTB: ENC1.P$B, U1.31 (GP26), U1.P$31 (GP26)
ROTSW: ENC1.P$1, U1.29 (GP22), U1.P$29 (GP22)
ROW1: D1.C, D2.C, D3.C, D4.C, U1.5 (GP3), U1.P$5 (GP3)
ROW2: D5.C, D6.C, D7.C, D8.C, D18.C, U1.4 (GP2), U1.P$4 (GP2)
ROW3: D9.C, D10.C, D11.C, D12.C, U1.2 (GP1), U1.P$2 (GP1)
ROW4: D13.C, D14.C, D15.C, D16.C, D17.C, U1.1 (GP0), U1.P$1 (GP0)
SW0: S1.4 (P1), U1.34 (GP28), U1.P$34 (GP28)
VBUS: U1.40 (VBUS), U1.P$40 (VBUS)
VSYS: U1.39 (VSYS), U1.P$39 (VSYS)

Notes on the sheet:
@todbot / Tod Kurt
https://github.com/todbot/picostepseq
RING2
RING1
GND
TIP

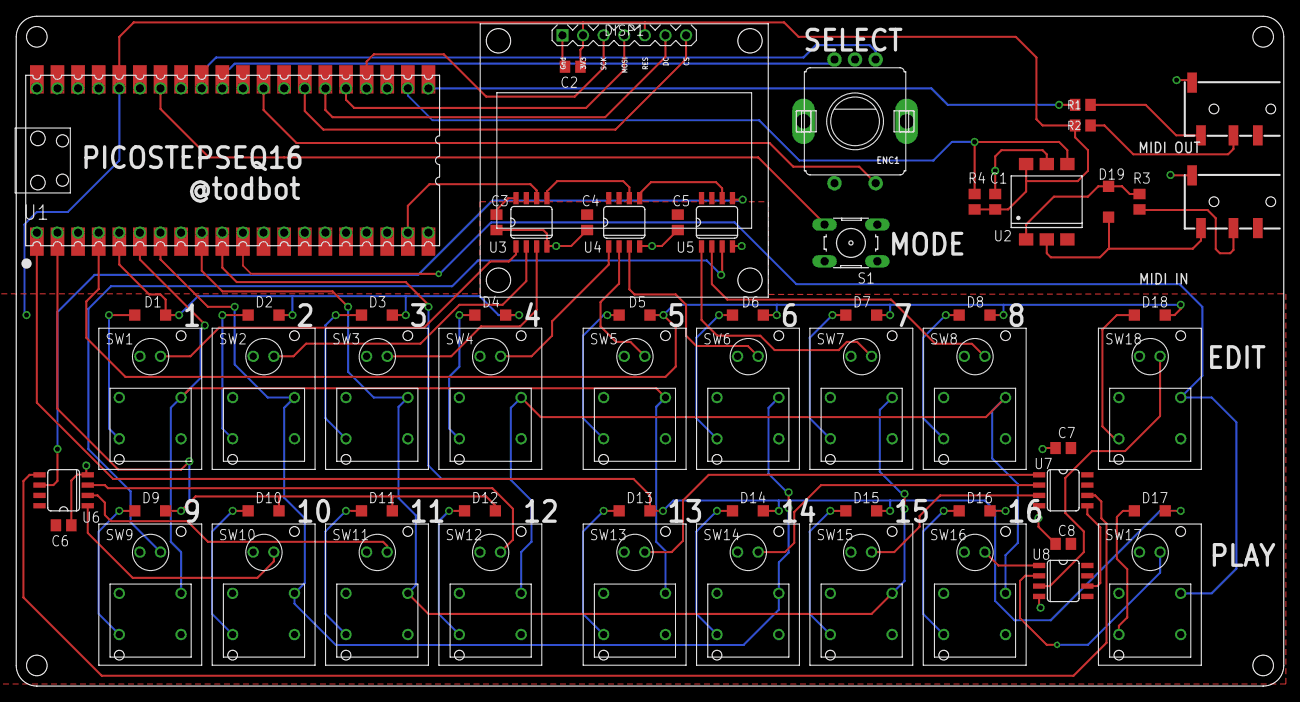
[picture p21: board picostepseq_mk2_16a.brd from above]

Board: 2 copper layers, 156.2 x 82.5 mm, 62 parts (0 on the bottom side), 70 nets.

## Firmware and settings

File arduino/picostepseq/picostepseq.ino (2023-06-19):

/**
 * picostepseq.ino  -- picostepseq MIDI step sequencer in Arduino
 * 28 Apr 2023 - @todbot / Tod Kurt
 * 15 Aug 2022 - @todbot / Tod Kurt
 * Part of https://github.com/todbot/picostepseq/
 *
 * Libraries needed (all available via Library Manager):
 * - Bounce2 -- https://github.com/thomasfredericks/Bounce2
 * - RotaryEncoder -- http://www.mathertel.de/Arduino/RotaryEncoderLibrary.aspx
 * - Adafruit_SSD1306 -- https://github.com/adafruit/Adafruit_SSD1306
 * - Adafruit_TinyUSB -- https://github.com/adafruit/Adafruit_TinyUSB_Arduino
 * - MIDI -- https://github.com/FortySevenEffects/arduino_midi_library
 * - ArduinoJson -- https://arduinojson.org/
 *
 * To upload:
 * - Use Arduino IDE 1.8.19
 * - Install arduino-pico Arduino core https://arduino-pico.readthedocs.io/en/latest/install.html
 * - In "Tools", set "Flash Size: 2MB (Sketch: 1MB / FS: 1MB)"
 * - In "Tools", set "Tools / USB Stack: Adafruit TinyUSB"
 * - Program the sketch to the Pico with "Upload"
 *
 **/

#include <Wire.h>
#include <RotaryEncoder.h>
#include <Bounce2.h>
#include <Adafruit_SSD1306.h>
#include <Adafruit_TinyUSB.h>
#include <MIDI.h>
#include <LittleFS.h>
#include <ArduinoJson.h>

#include "fonts/helvnCB6pt7b.h"
#include "fonts/ter_u12n7b.h"  // CirPy's default displayio font, it seems

#include "Sequencer.h"
#include "saved_sequences_json.h"  // to bootstrap the "saved_sequences.json" file

#define myfont helvnCB6pt7b  // sigh
#define myfont2 ter_u12n7b

typedef struct {
  int  step_size;  // aka "seqr.ticks_per_step"
  int  midi_chan;
  int  midi_velocity;
  bool midi_send_clock;
  bool midi_forward_usb;
  bool midi_forward_uart;
} Config;

Config cfg  = {
  //.step_size = SIXTEENTH_NOTE,
  .step_size = EIGHTH_NOTE,
  .midi_chan = 1,
  .midi_velocity = 80,
  .midi_send_clock = true,
  .midi_forward_usb = true,
  .midi_forward_uart = true,
};

const char* save_file = "/saved_sequences.json";
const bool midi_out_debug = true;
const bool midi_in_debug = true;

const int numseqs = 8;

// begin hardware definitions
const int dw = 128;
const int dh = 64;

const int led_pins[] = { 0, 2, 4, 6, 8, 10, 12, 14 };
const int key_pins[] = { 1, 3, 5, 7, 9, 11, 13, 15 };

const int encoderA_pin = 18;
const int encoderB_pin = 19;
const int encoderSW_pin = 22;

const int oled_sda_pin = 20;
const int oled_scl_pin = 21;

const int oled_i2c_addr = 0x3C;

const int midi_tx_pin = 16;
const int midi_rx_pin = 17;
// end hardware definitions

Adafruit_USBD_MIDI usb_midi;                                  // USB MIDI object
MIDI_CREATE_INSTANCE(Adafruit_USBD_MIDI, usb_midi, MIDIusb);  // USB MIDI
MIDI_CREATE_INSTANCE(HardwareSerial, Serial1, MIDIuart);      // Serial MIDI

Adafruit_SSD1306 display(dw, dh, &Wire, -1);

Bounce2::Button keys[numsteps];
Bounce2::Button encoder_switch;

RotaryEncoder encoder(encoderB_pin, encoderA_pin, RotaryEncoder::LatchMode::FOUR3);
void checkEncoderPosition() {  encoder.tick();  } // call tick() to check the state.
int encoder_pos_last = 0;

int led_vals[numsteps];
int led_fade = 85;

float tempo = 100;
StepSequencer seqr;
Step sequences[numseqs][numsteps];

uint8_t midiclk_cnt = 0;
uint32_t midiclk_last_micros = 0;


#include "saveload.h" /// FIXME:

//
// -- MIDI sending & receiving functions
//

// callback used by Sequencer to trigger note on
void send_note_on(uint8_t note, uint8_t vel, uint8_t gate, bool on) {
  if (on) {
    MIDIusb.sendNoteOn(note, cfg.midi_velocity, cfg.midi_chan);
    MIDIuart.sendNoteOn(note, cfg.midi_velocity, cfg.midi_chan);
  }
  if (midi_out_debug) { Serial.printf("noteOn:  %d %d %d %d\n", note, vel, gate, on); }
}

// callback used by Sequencer to trigger note off
void send_note_off(uint8_t note, uint8_t vel, uint8_t gate, bool on) {
  if (on) {
    MIDIusb.sendNoteOff(note, cfg.midi_velocity, cfg.midi_chan);
    MIDIuart.sendNoteOff(note, cfg.midi_velocity, cfg.midi_chan);
  }
  if (midi_out_debug) { Serial.printf("noteOff: %d %d %d %d\n", note, vel, gate, on); }
}

// callback used by Sequencer to send midi clock when internally triggered
void send_clock_start_stop(clock_type_t type) {
  if (type == START) {
    MIDIusb.sendStart();
    MIDIuart.sendStart();
  } else if (type == STOP) {
    MIDIusb.sendStop();
    MIDIuart.sendStop();
  } else if (type == CLOCK) {
    MIDIusb.sendClock();
    MIDIuart.sendClock();
  }
  if (midi_out_debug) { Serial.printf("\tclk:%d\n", type); }
}

// void handle_midi_in_songpos(unsigned int beats) {
//     Serial.printf("songpos:%d\n", beats);
//     if( beats == 0 ) {
//         seqr.stepi = 0;
//     }
// }

void handle_midi_in_start() {
  seqr.play();
  midiclk_cnt = 0;
  if (midi_in_debug) { Serial.println("midi in start"); }
}

void handle_midi_in_stop() {
  seqr.stop();
  if (midi_in_debug) { Serial.println("midi in stop"); }
}

// FIXME: midi continue?
void handle_midi_in_clock() {
  uint32_t now_micros = micros();
  //const int fscale = 230; // out of 255, 230/256 = .9 filter
  // once every ticks_per_step, play note (24 ticks per quarter note => 6 ticks per 16th note)
  if (midiclk_cnt % seqr.ticks_per_step == 0) {  // ticks_per_step = 6 for 16th note
    seqr.trigger_ext(now_micros);  // FIXME: figure out 2nd arg (was step_millis)
  }
  midiclk_cnt++;
  // once every quarter note, calculate new BPM, but be a little cautious about it
  if( midiclk_cnt == ticks_per_quarternote ) {
      uint32_t new_tick_micros = (now_micros - midiclk_last_micros) / ticks_per_quarternote;
      if( new_tick_micros > seqr.tick_micros/2 && new_tick_micros < seqr.tick_micros*2 ) {
        seqr.tick_micros = new_tick_micros;
      }
      midiclk_last_micros = now_micros;
      midiclk_cnt = 0;
  }
}

//
void midi_read_and_forward() {
  if (MIDIusb.read()) {
    midi::MidiType t = MIDIusb.getType();
    switch (t) {
      case midi::Start:
        handle_midi_in_start();  break;
      case midi::Stop:
        handle_midi_in_stop();  break;
      case midi::Clock:
        handle_midi_in_clock();  break;
      default: break;
    }
    // forward the midi msg to other port
    MIDIuart.send(t, MIDIusb.getData1(), MIDIusb.getData2(), MIDIusb.getChannel());
  }

  if (MIDIuart.read()) {
    midi::MidiType t = MIDIuart.getType();
    switch (t) {
      case midi::Start:
        handle_midi_in_start();  break;
      case midi::Stop:
        handle_midi_in_stop();  break;
      case midi::Clock:
        handle_midi_in_clock();  break;
      default: break;
    }
    MIDIusb.send(t, MIDIuart.getData1(), MIDIuart.getData2(), MIDIuart.getChannel());
  }
}

////////////////////////////

//
// ---  MIDI in/out setup on core0
//
void setup() {
  TinyUSBDevice.setManufacturerDescriptor("todbot");
  TinyUSBDevice.setProductDescriptor("PicoStepSeq");

  Serial1.setRX(midi_rx_pin);
  Serial1.setTX(midi_tx_pin);

  MIDIusb.begin();
  MIDIusb.turnThruOff();   // turn off echo
  MIDIuart.begin(MIDI_CHANNEL_OMNI); // don't forget OMNI
  MIDIuart.turnThruOff();  // turn off echo

  Serial.begin(115200);
}

//
// --- MIDI in/out on core0
//
void loop() {
  midi_read_and_forward();
  seqr.update();  // will call send_note_{on,off} callbacks
}

void configure_sequencer() {
  Serial.println("configuring sequencer");
  seqr.set_tempo(tempo);
  seqr.ticks_per_step = cfg.step_size;
  seqr.on_func = send_note_on;
  seqr.off_func = send_note_off;
  seqr.clk_func = send_clock_start_stop;
  seqr.send_clock = cfg.midi_send_clock;
};

//
// --- UI setup on core1 (buttons, knobs, display, LEDs)
//
void setup1() {
  // delay(5000);  // for debugging

  LittleFS.begin();

  sequences_read();
  sequence_load(seqr.seqno);  // 0

  configure_sequencer();

  // KEYS
  for (uint8_t i = 0; i < numsteps; i++) {
    keys[i].attach(key_pins[i], INPUT_PULLUP);
    keys[i].setPressedState(LOW);
  }

  // LEDS
  for (uint8_t i = 0; i < numsteps; i++) {
    pinMode(led_pins[i], OUTPUT);
    analogWrite(led_pins[i], i * 10);  // just to test
  }

  // ENCODER
  pinMode(encoderA_pin, INPUT_PULLUP);
  pinMode(encoderB_pin, INPUT_PULLUP);
  attachInterrupt(digitalPinToInterrupt(encoderA_pin), checkEncoderPosition, CHANGE);
  attachInterrupt(digitalPinToInterrupt(encoderB_pin), checkEncoderPosition, CHANGE);
  encoder_switch.attach(encoderSW_pin, INPUT_PULLUP);
  encoder_switch.setPressedState(LOW);

  // DISPLAY
  Wire.setSDA(oled_sda_pin);
  Wire.setSCL(oled_scl_pin);
  Wire.begin();

  if (!display.begin(SSD1306_SWITCHCAPVCC, oled_i2c_addr)) {
    Serial.println(F("SSD1306 allocation failed"));
    for (;;) ;  // Don't proceed, loop forever
  }

  displaySplash();
  displayConfig();
  delay(1000);
}

/**
 * Let's talk about UI input "verbs".  This is what we got:
 *
 * encoder tap                -- play/stop
 * encoder pushhold           -- modifier for combo
 * encoder turn               -- transpose
 * encoder pushhold + turn    -- bpm
 *
 * key tap                    -- mute/unmute or play step
 * key hold                   -- modifier for combo ()
 *
 * key hold + encoder turn
 * key hold + encoder tap  (unused)
 * key hold + encoder pushhold + encoder turn
 *
 * encoder hold + key tap
 * encoder hold + key hold
 * encoder hold + key hold + encoder turn (currently unused)
 *
 */

// variables for UI state management
int encoder_delta = 0;
uint32_t encoder_push_millis;
bool encoder_held = true;
uint32_t step_push_millis;
//bool steps_pushed[numsteps]; // which keys are pressed
int step_push = -1;
bool step_edited = false;
char seq_info[11];  // 10 chars + nul FIXME

enum {
  MODE_PLAY = 0,
  MODE_CONFIG,
  MODE_COUNT   // how many modes we got
};

enum {
  CFG_STEPSIZE = 0,
  CFG_MIDICHAN,
  CFG_MIDIVEL,
  CFG_MIDISENDCLK,
  CFG_COUNT
};

int display_mode = MODE_PLAY;
int cfg_selected = -1; // one of config_selected
//int cfg_i = 0; // arbitrary counter to be used by whatever config is selected

//
// --- UI handling on core1
//
void loop1() {
  // LEDS update
  for (int i = 0; i < numsteps; i++) {
    Step s = seqr.steps[i];
    int v = 0;                         // UI: off = muted
    int si = (seqr.stepi-0) % numsteps;
    if (i == si) { v = 255; }  // UI: bright red = indicates sequence postion
    else if (s.on) {
      v = 40;
    }                                    // UI: dim red = indicates mute/unmute state
    v = max(led_vals[i] - led_fade, v);  // nice 80s fade
    led_vals[i] = v;
    analogWrite(led_pins[i], v);
  }

  // ENCODER update
  encoder_switch.update();
  encoder.tick();
  int encoder_pos = encoder.getPosition();
  if (encoder_pos != encoder_pos_last) {
    encoder_delta = encoder_pos - encoder_pos_last;
    encoder_pos_last = encoder_pos;
  }

  uint32_t now = millis();

  if (encoder_push_millis > 0 ) {
    if (!step_push_millis && (now-encoder_push_millis) > 1000 && !encoder_delta ) {
      if( !encoder_held ) {
        encoder_held = true;
        display_mode =  (display_mode + 1) % MODE_COUNT;
        if( display_mode == MODE_PLAY ) { // switched back to play mode
          configure_sequencer();
        }
      }
    }
    if (step_push_millis > 0) { // we're pushing a step key too
      if (encoder_push_millis < step_push_millis) {  // and encoder was pushed first
        strcpy(seq_info, "saveseq");
      }
    }
  }

  // on encoder turn
  if (encoder_delta) {
    // UI: encoder turn + push while step key held = change step's gate
    if (step_push > -1 && encoder_push_millis > 0) {
      //key_with_turn_push(encoder_delta);
      int gate = seqr.steps[step_push].gate;
      gate = constrain(gate + encoder_delta, 1, 15);
      seqr.steps[step_push].gate = gate;
      step_edited = true;
    }
    // UI: encoder turn while step key held = change step's note
    else if (step_push > -1) {
      Step s = seqr.steps[step_push];
      if (!seqr.playing) {  // step preview note off
        send_note_off(s.note, s.vel, s.gate, true);
      }
      s.note = constrain(s.note + encoder_delta, 1, 127);
      if (!seqr.playing) {  // step preview note on
        send_note_on(s.note, s.vel, s.gate, true);
      }
      seqr.steps[step_push] = s;
      step_edited = true;
    }
    // UI: encoder turn while encoder pushed = change tempo
    else if (encoder_push_millis > 0) {
      tempo = tempo + encoder_delta;
      seqr.set_tempo(tempo);
      Serial.printf("TEMPO: %d %f\n", (int)seqr.tempo(), seqr.tempo());
    }
    // UI: encoder turn = change transpose
    else {
      if( display_mode == MODE_PLAY ) { // play screene
        seqr.transpose = constrain(seqr.transpose + encoder_delta, -36, 36);
      }
      else if (display_mode == MODE_CONFIG) {
        if (cfg_selected==CFG_STEPSIZE) { // ugh
          if( (encoder_delta >0 && cfg.step_size == QUARTER_NOTE) ||
              (encoder_delta <0 && cfg.step_size == SIXTEENTH_NOTE) ) {
            cfg.step_size = EIGHTH_NOTE;
          }
          else if( (encoder_delta >0 && cfg.step_size == EIGHTH_NOTE) ||
                   (encoder_delta <0 && cfg.step_size == QUARTER_NOTE) ) {
            cfg.step_size = SIXTEENTH_NOTE;
          }
          else if( (encoder_delta >0 && cfg.step_size == SIXTEENTH_NOTE) ||
                   (encoder_delta <0 && cfg.step_size == EIGHTH_NOTE) ) {
            cfg.step_size = QUARTER_NOTE;
          }
          configure_sequencer();
        }
        else if(cfg_selected == CFG_MIDICHAN) {
          cfg.midi_chan = constrain( 1 + ((cfg.midi_chan-1) + encoder_delta) % 16, 1,16);
        }
        else if(cfg_selected == CFG_MIDIVEL) {
          cfg.midi_velocity = constrain( 1 + ((cfg.midi_velocity-1) + (encoder_delta*2)) % 127, 1,127);
        }
        else if(cfg_selected == CFG_MIDISENDCLK) {
          cfg.midi_send_clock = (cfg.midi_send_clock + 1) % 2; // on/off
        }
      }
    }
    encoder_delta = 0;  // we own turning, and we've used it
  }

  // on encoder push
  if (encoder_switch.pressed()) {  // push encoder button
    encoder_push_millis = now;     // save when (and that) it was pushed
  }

  if (encoder_switch.released()) {                // release encoder button
    if (step_push == -1 && encoder_delta == 0) {  // step key is not pressed and no encoder turn
      if( display_mode == MODE_PLAY ) { // play screen
        // UI: encoder tap with no key == play/pause
        if (now - encoder_push_millis < 300) {
          seqr.toggle_play_stop();
          delay(10);  // wait a bit for sequencer to change state
          if (!seqr.playing) {
            sequences_write();  // write to disk on pause
          }
        }
      }
      else if( display_mode == MODE_CONFIG ){ // config screen
        cfg_selected = (cfg_selected + 1) % CFG_COUNT;
        // FIXME: need to load config
      }
    }
    encoder_held = 0;
    encoder_push_millis = 0;  // we own it, and we're done with it
  }

  // KEYS update

  // press/release event check
  for (uint8_t i = 0; i < numsteps; i++) {
    keys[i].update();
    Step s = seqr.steps[i];

    if (keys[i].pressed()) {  // press event
      step_push = i;
      step_push_millis = now;

      if (encoder_push_millis > 0) { // not pushing encoder
        // do nothing
      } else {
        if (!seqr.playing) {
          send_note_on(s.note, s.vel, s.gate, true);
        }
      }
    }

    else if (keys[i].released()) {    // release event
      if (encoder_push_millis > 0) {  // UI: load/save sequence mode
        // UI: encoder push + hold step key = save sequence
        if (now - step_push_millis > 1000) {
          sequence_save(step_push);
          strcpy(seq_info, "");
        }
        // UI: encoder push + tap step key = load sequence
        else {
          sequence_load(step_push);
        }
      } else {  // UI: encoder not pushed, mutes or play notes
        // UI: playing: step keys = mutes/unmutes
        if (seqr.playing) {
          if (step_edited) {
          } else {
            // UI: if playing, step keys == mute/unmute toggle
            seqr.steps[i].on = !seqr.steps[i].on;
          }
        }
        // UI: paused: step keys = play step notes
        else {
          send_note_off(s.note, s.vel, s.gate, true);
        }
      }
      step_push_millis = 0;
      step_push = -1;  //
      step_edited = false;
    }
  }

  // DISPLAY update
  if (display_mode == MODE_CONFIG) {
    displayConfig();
  }
  else if( display_mode == MODE_PLAY) {
    displayUpdate(step_push);
  }
}


//
// --- display details
//
typedef struct { int x; int y;  const char* str;} pos_t;

//// {x,y} locations of play screen items
const int step_text_pos[] = { 0, 15, 16, 15, 32, 15, 48, 15, 64, 15, 80, 15, 96, 15, 112, 15 };
const pos_t bpm_text_pos    = {.x=0,  .y=57, .str="bpm:%3d" };
const pos_t trans_text_pos  = {.x=55, .y=57, .str="trs:%+2d" };
const pos_t seqno_text_pos  = {.x=0,  .y=45, .str="seq:%d" };
const pos_t seq_info_pos    = {.x=60, .y=45, .str="" };
const pos_t play_text_pos   = {.x=110,.y=57, .str="" };

const pos_t oct_text_offset = { .x=3, .y=10,  .str="" };
const pos_t gate_bar_offset = { .x=0, .y=-15, .str="" };
const pos_t edit_text_offset= { .x=3, .y=22,  .str="" };
const int gate_bar_width = 14;
const int gate_bar_height = 4;

const char* note_strs[] = { "C ", "C#", "D ", "D# ", "E ", "F ", "F#", "G ", "G#", "A ", "A#", "B ", "C " };

int notenum_to_oct(int notenum) {
  return (notenum / 12) - 2;
}
const char* notenum_to_notestr(int notenum) {
  return note_strs[notenum % 12];
}

void displayUpdate(int selected_step) {
  display.clearDisplay();
  display.setFont(&myfont);
  display.setTextColor(WHITE, 0);
  for (int i = 0; i < numsteps; i++) {
    Step s = seqr.steps[i];
    const char* nstr = notenum_to_notestr(s.note);
    int o = notenum_to_oct(s.note);
    int x = step_text_pos[i * 2], y = step_text_pos[i * 2 + 1];
    display.setCursor(x, y);
    display.print(nstr);
    display.setCursor(x + oct_text_offset.x, y + oct_text_offset.y);
    display.printf("%1d", o);
    display.setCursor(x + edit_text_offset.x, y + edit_text_offset.y);
    display.print((i == selected_step) ? '^' : (s.on) ? ' '
                                                      : '*');
    int gate_w = 1 + (s.gate * gate_bar_width / 16);
    display.fillRect(x + gate_bar_offset.x, y + gate_bar_offset.y, gate_w, gate_bar_height, WHITE);
  }

  display.setFont(&myfont2);

  // bpm
  display.setCursor(bpm_text_pos.x, bpm_text_pos.y);
  display.printf(bpm_text_pos.str, (int)(seqr.tempo()));

  // transpose
  display.setCursor(trans_text_pos.x, trans_text_pos.y);
  display.printf(trans_text_pos.str, seqr.transpose);

  // seqno
  display.setCursor(seqno_text_pos.x, seqno_text_pos.y);
  display.printf(seqno_text_pos.str, seqr.seqno + 1);  // user sees 1-8

  // seq info / meta
  display.setCursor(seq_info_pos.x, seq_info_pos.y);
  display.print(seq_info);

  // play/pause
  display.setCursor(play_text_pos.x, play_text_pos.y);
  display.print(seqr.playing ? " >" : "[]");

  display.display();
}

// {x,y} locations of config screen
const pos_t stepsize_text_pos    = {.x=5, .y=12, .str="step size: %s"};
const pos_t midichan_text_pos    = {.x=5, .y=24, .str="midi ch:   %d"};
const pos_t midivel_text_pos     = {.x=5, .y=36, .str="midi vel:  %d"};
const pos_t midisendclk_text_pos = {.x=5, .y=48, .str="midi sendclk: %s"};

void displayConfig() {
  display.clearDisplay();
  display.setFont(&myfont2);
  display.setTextColor(WHITE, 0);

  if(cfg_selected == CFG_STEPSIZE) {
    display.drawRect( stepsize_text_pos.x-4, stepsize_text_pos.y-11, 125, 14, WHITE );
  }
  display.setCursor( stepsize_text_pos.x, stepsize_text_pos.y);
  const char* sstr = (cfg.step_size==SIXTEENTH_NOTE) ? "1/16" : (cfg.step_size==EIGHTH_NOTE) ? "1/8 " : "1/4 ";
  display.printf(stepsize_text_pos.str, sstr);


  if(cfg_selected == CFG_MIDICHAN) {
    display.drawRect( midichan_text_pos.x-4, midichan_text_pos.y-11, 125, 14, WHITE );
  }
  display.setCursor( midichan_text_pos.x, midichan_text_pos.y);
  display.printf(midichan_text_pos.str, cfg.midi_chan);

  if(cfg_selected == CFG_MIDIVEL) {
    display.drawRect( midivel_text_pos.x-4, midivel_text_pos.y-11, 125, 14, WHITE );
  }
  display.setCursor( midivel_text_pos.x, midivel_text_pos.y);
  display.printf(midivel_text_pos.str, cfg.midi_velocity);

  if(cfg_selected == CFG_MIDISENDCLK) {
    display.drawRect( midisendclk_text_pos.x-4, midisendclk_text_pos.y-11, 125, 14, WHITE );
  }
  display.setCursor( midisendclk_text_pos.x, midisendclk_text_pos.y);
  display.printf(midisendclk_text_pos.str, cfg.midi_send_clock ? "on":"off");

  display.display();
}

void displaySplash() {
  display.clearDisplay();
  display.setFont(&myfont2);
  display.setTextColor(WHITE, 0);
  display.drawRect(0,0, dw-1, dh-1, WHITE);
  display.setCursor(25, 32);
  display.print("PICOSTEPSEQ");
  display.display();
  // a little LED dance
  for( int i=0; i<1000; i++) {
    for( int j=0; j<numsteps; j++) {
      int v = 30 + 30 * sin( (j*6.2 / 8 ) + i/50.0 ) ;
      analogWrite( led_pins[j], v);
    }
    delay(1);
  }
}

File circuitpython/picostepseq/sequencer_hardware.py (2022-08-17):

# sequencer_hardware.py -- picostepseq hardware specific setup
# 10 Aug 2022 - @todbot / Tod Kurt
# Part of picostepseq : https://github.com/todbot/picostepseq/


import board
import busio
import pwmio
import rotaryio
import keypad
import displayio
import adafruit_displayio_ssd1306

dw,dh = 128,64

led_pins = (board.GP0, board.GP2, board.GP4, board.GP6,
            board.GP8, board.GP10, board.GP12, board.GP14)

key_pins = (board.GP1, board.GP3, board.GP5, board.GP7,
            board.GP9, board.GP11, board.GP13, board.GP15)

encoderA_pin, encoderB_pin, encoderSW_pin = board.GP18, board.GP19, board.GP22

oled_sda_pin, oled_scl_pin = board.GP20, board.GP21

midi_tx_pin, midi_rx_pin = board.GP16, board.GP17

def make_led(p): po = pwmio.PWMOut(p, frequency=25000, duty_cycle=0); return po

class Hardware():
    def __init__(self):
        # KEYS
        self.keys = keypad.Keys(key_pins, value_when_pressed=False, pull=True)
        self.step_to_key_pos = (0,1,2,3,4,5,6,7)

        # LEDS
        # create the objects handling those pin functions
        self.leds = [ make_led(p) for p in led_pins ]
        self.leds_fade_amount = 30

        # KNOB
        self.encoder = rotaryio.IncrementalEncoder(encoderA_pin, encoderB_pin)
        self.encoder_switch = keypad.Keys((encoderSW_pin,), value_when_pressed=False, pull=True)

        # DISPLAY
        oled_i2c = busio.I2C( scl=oled_scl_pin, sda=oled_sda_pin, frequency=400_000 )
        display_bus = displayio.I2CDisplay(oled_i2c, device_address=0x3C)  # or 0x3D depending on display
        self.display = adafruit_displayio_ssd1306.SSD1306(display_bus, width=dw, height=dh)

        # # uart midi setup
        #midi_timeout = 0.01
        self.midi_uart = busio.UART(tx=midi_tx_pin, rx=midi_rx_pin, baudrate=31250) # timeout=midi_timeout)

    # set LED brightness to value from 0-255
    def led_set(self,i,v):
        self.leds[i].duty_cycle = v * 256  # duty_cycle 0-65535

    # get LED brightness to value 0-255
    def led_get(self,i):
        return self.leds[i].duty_cycle // 256

    # refresh all LEDs (if meaningful)
    def leds_show(self):
        pass

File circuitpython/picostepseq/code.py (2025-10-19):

# picostepseq_code.py -- picostepseq MIDI step sequencer
# 6 Aug 2022 - @todbot / Tod Kurt
# Part of picostepseq: https://github.com/todbot/picostepseq/
#
# User interface:
#
# - Play / Pause -- tap encoder button
# - Transpose sequence -- turn encoder knob
# - Change tempo -- push + turn encoder knob
#
# - Mute / Unmute steps -- tap corresponding step key (while playing)
# - Play notes -- tap corresponding step key (while paused)
# - Change step pitch -- hold step key, turn encoder knob
# - Change step gate -- hold step key, push + turn encoder knob
# - Change sequence -- push encoder, tap step key 1-8, release encoder
# - Save sequence -- push encoder, hold step key 1-8 for 2 secs, release encoder

#
# Or from the device point-of-view:
#
# "Encocder-first" actions:
# - Tap encoder to toggle play / pause
# - Turn encoder to change tranpose
# - Push + turn encoder to change transpose
# - Push encoder + push step key to load sequence 1-8
# - Hold encoder + hold step key > 1 sec to save sequence 1-8
# - Sequences saved to disk on pause
# "Step key-first" actions:
# - Tap step button to enable/disable from sequence
# - Hold step button + turn encoder to change note
# - Hold step button + push encoder + turn encoder to change gate length
#

# built in libraries
import board
import gc
import json
import usb_midi

# local libraries in CIRCUITPY
import winterbloom_smolmidi as smolmidi
from sequencer import StepSequencer, ticks_ms

if 'macropad' in board.board_id:
    from sequencer_display_macropad import SequencerDisplayMacroPad as SequencerDisplay
    from sequencer_hardware_macropad import Hardware
else:
    import displayio
    displayio.release_displays() # can we put this in sequencer_hardware?
    from sequencer_display import SequencerDisplay
    from sequencer_hardware import Hardware

do_usb_midi = True
do_serial_midi = True

playdebug = False

midi_chan = 1
base_note = 60  #  60 = C4, 48 = C3
num_steps = 8
tempo = 100
gate_default = 8    # ranges 0-15

# array of sequences used by Sequencer (which only knows about one sequence)
sequences = [ [(None)] * num_steps ] * num_steps  # pre-fill arrays for easy use later


usb_out = usb_midi.ports[1]
usb_in = usb_midi.ports[0]

usb_midi_in = smolmidi.MidiIn(usb_in)


midiclk_cnt = 0
midiclk_last_millis = 0
def midi_receive():
    """Handle MIDI Clock and Start/Stop"""
    global midiclk_cnt, midiclk_last_millis

    msg = usb_midi_in.receive()

    if not msg: return

    if msg.type == smolmidi.START:
        print("MIDI START")
        seqr.play()
        seqr_display.update_ui_playing()

    elif msg.type == smolmidi.STOP:
        print("MIDI STOP")
        seqr.stop()
        seqr_display.update_ui_playing()

    elif msg.type == smolmidi.CLOCK:
        midiclk_cnt += 1
        if midiclk_cnt % 6 == 0:  # once every 1/16th note (24 pulses per quarter note => 6 pulses per 16th note)
            now = ticks_ms()
            seqr.trigger_next(now)

            if midiclk_cnt % 24 == 0:  # once every quarter note
                beat_millis = (now - midiclk_last_millis) / 4  # beat_millis is 1/16th note time
                midiclk_last_millis = now
                seqr.beat_millis = beat_millis
                seqr_display.update_ui_bpm()
                seqr_display.update_ui_playing()


def play_note_on(note, vel, gate, on):  #
    """Callback for sequencer when note should be turned on"""
    if not on: return
    if playdebug: print("on :%d n:%3d v:%3d %d %d" % (note,vel, gate,on), end="\n" )
    midi_status = 0x90 | (midi_chan-1)
    midi_msg = bytearray([midi_status, note, vel])
    if do_usb_midi:
        usb_out.write( midi_msg )
    if do_serial_midi:
        hw.midi_uart.write( midi_msg )

def play_note_off(note, vel, gate, on):  #
    """Callback for sequencer when note should be turned off"""
    #if on: # FIXME: always do note off to since race condition of note muted right after playing
    if playdebug: print("off:%d n:%3d v:%3d %d %d" % (note,vel, gate,on), end="\n" )
    midi_status = 0x80 | (midi_chan-1)
    midi_msg = bytearray([midi_status, note, vel])
    if do_usb_midi:
        usb_out.write( midi_msg )
    if do_serial_midi:
        hw.midi_uart.write( midi_msg )

def sequence_load(seq_num):
    """Load a single sequence into the sequencer from RAM storage"""
    new_seq = sequences[seq_num].copy()
    seqr.steps = new_seq
    seqr.seqno = seq_num

def sequence_save(seq_num):
    """Store current sequence in sequencer to RAM storage"""
    sequences[seq_num] = seqr.steps.copy()

def sequences_read():
    """Read entire sequence set from disk into RAM"""
    global sequences
    print("READING ALL SEQUENCES")
    with open('/saved_sequences.json', 'r') as fp:
        sequences = json.load(fp)

last_write_time = ticks_ms()
def sequences_write():
    """Write  entire sequence set from RAM to disk"""
    global last_write_time
    if ticks_ms() - last_write_time < 20000: # only allow writes every 10 seconds
        print("NO WRITE: TOO SOON")
        return
    last_write_time = ticks_ms()
    print("WRITING ALL SEQUENCES")
    with open('/saved_sequences.json', 'w') as fp:
        json.dump(sequences, fp)


hw = Hardware()

seqr = StepSequencer(num_steps, tempo, play_note_on, play_note_off, playing=False)

sequences_read()

seqr_display = SequencerDisplay(seqr)
hw.display.root_group = seqr_display

sequence_load(0)

# init display UI
seqr_display.update_ui_all()

# various state for UI handling
encoder_val_last = hw.encoder.position # needed to calculate encoder_delta
encoder_push_millis = 0  # when was encoder pushed, 0 == no push
encoder_delta = 0  # how much encoder was turned, 0 == no turn
step_push = -1  # which step button is being pushed, -1 == no push
step_push_millis = 0  # when was a step button pushed
step_edited = False  # was a step edited while it was held?

print("Ready.")
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

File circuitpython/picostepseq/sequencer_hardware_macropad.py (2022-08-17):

# sequencer_hardware_macropad.py -- picostepseq hardware specific setup for MacroPad 2040
# 10 Aug 2022 - @todbot / Tod Kurt
# Part of picostepseq : https://github.com/todbot/picostepseq/

import board
import busio
import rotaryio
import keypad
import neopixel

dw,dh = 128,64

key_pins = [getattr(board, "KEY%d" % (num + 1)) for num in range(0,12)]

encoderA_pin, encoderB_pin, encoderSW_pin = board.ROTA, board.ROTB, board.BUTTON

midi_tx_pin, midi_rx_pin = board.SDA, board.SCL

class Hardware():
    def __init__(self):
        # KEYS
        self.keys = keypad.Keys(key_pins, value_when_pressed=False, pull=True)
        self.step_to_key_pos = (1, 4, 7, 10, 0, 3, 6, 9)

        # LEDS
        self.leds = neopixel.NeoPixel(board.NEOPIXEL, 12)
        self.leds.brightness = 0.2
        self.leds.auto_write = False
        self.leds_fade_amount = 50

        # KNOB
        self.encoder = rotaryio.IncrementalEncoder(encoderB_pin, encoderA_pin)  # yes, reversed
        self.encoder_switch = keypad.Keys((encoderSW_pin,), value_when_pressed=False, pull=True)

        # DISPLAY
        self.display = board.DISPLAY
        self.display.rotation = 90

        # uart midi setup
        self.midi_uart = busio.UART(tx=midi_tx_pin, rx=midi_rx_pin, baudrate=31250) # timeout=midi_timeout)

    # set LED brightness to value from 0-255
    def led_set(self,i,v):
        #print("i",i)
        self.leds[ self.step_to_key_pos[i] ] = (v, 0,0)
        #self.leds[ i ] = (v, 0,0)

    # get LED brightness to value 0-255
    def led_get(self,i):
        c = self.leds[ self.step_to_key_pos[i] ]
        #c = self.leds[ i ]
        return c[0]

    # refresh all LEDs (if meaningful)
    def leds_show(self):
        self.leds.show()

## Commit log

2022-08-06 sigh trs-a/b will kill me
    [picostepseq.brd, picostepseq.sch]
2022-08-06 update to knob
    [picostepseq.brd, picostepseq.sch]
2022-08-06 small fixes, submit to fab
    [picostepseq.brd]
2022-08-09 redesign LED update method, encoder knob push hold to stop finally works
    [code.py, step_sequencer.py]
2022-08-10 fix play/pause bug, fix mute/unmute bug, fix playing when stopped bug
    [code.py, sequencer.py]
2022-08-10 move MIDI IN and MIDI OUT labels because I am dumb
    [picostepseq.brd, picostepseq.sch]
2022-08-12 fix lag from big i2c ssd1306 updates
    [code.py, sequencer_display.py]
2022-08-15 midi beat sync does not work yet
    [code.py, sequencer.py, sequencer_display.py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]
2022-08-17 update readme with bom
    [picostepseq.sch, picostepseq_bom.csv]
2022-08-18 update stl, update gerbers
    [picostepseq_case_top.stl]
2022-08-18 add arduino test
2022-08-18 add spacer for oled
    [picostepseq_case_oledspacer.stl]
2022-08-18 fix arduino hardware test display
    [hardware_test.ino]
2022-08-19 arduino test, added font
2022-08-19 slight circuitpython reorg
2022-08-19 arduino test: use a debouncer
2022-08-21 arduino: basic UI functionality
    [picostepseq_case_top_short.stl]
2022-08-21 arduino version now close to circuitpython version, feature-wise
2022-08-22 remove extranous prints, elapsed time printer, comments
2022-08-22 circuitpython: reduce lag when updating transpose by separating text & value
2022-08-22 arduino: note preview working
2022-08-22 arduino now has edit/mute display
2022-08-24 added some assembly pics
2022-08-24 rename assembly pics
2022-08-24 update PCB info about gerbers
2022-08-25 add taller version of top STL
    [picostepseq_case_top.stl]
2022-10-14 commit 16-ch idea
    [picostepseq_mk2_16.brd, picostepseq_mk2_16.sch]
2022-11-24 "finish" picostepseq_mk2_16
    [picostepseq_mk2_16.brd, picostepseq_mk2_16.sch]
2023-02-15 add diode to original picostepseq board, submit fab run
    [picostepseq1a.brd, picostepseq1a.sch, picostepseq_mk2_16.brd]
2023-03-10 smd-ish version of picostepseq16
    [picostepseq_mk2_16a.brd, picostepseq_mk2_16a.sch]
2023-04-21 arduino: describe how to actually install arduino version; make more obvious which MIDI channel is sends on; prefill sequence with random (and non-zero velocity) sequence data if "saved_sequences.jso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
2023-04-21 arduino: cleanup, add rudimentary midi clock receive that even mostly works
2023-04-22 arduino: uart midi in clock sync, small display cleanup
2023-04-22 circuitpython: note how to install libraries. fixes #1
2023-04-22 just turning some of the brd layers on
    [picostepseq1a.brd]
2023-04-22 arduino: match display mutes to CirPy version
2023-04-28 arduino: midiclock out and in
2023-04-28 arduino: try to figure out small lag in midi notes with clockout
2023-04-28 arduino: default sequences generated on first run, no need for data dir any more. midi clock forward (untested)
2023-04-30 arduino: midi forward, and cleanup
2023-04-30 arduino: fix midi forward (OMNI!) and other cleanup, prepping for config screen
    [picostepseq.ino, sequencer.h]
2023-05-01 arduino: fix midi in clock tempo calc; add config struct for future use, badly implemented config screen, display pos_t struct
    [picostepseq.ino]
2023-05-02 arduino: still having issues with first notes not turning off when midi in clock
    [picostepseq.ino, sequencer.h]
2023-05-02 arduino: fixed first time midi clocked notes
    [sequencer.h]
2023-05-02 arduino: sequencer.h retab
2023-05-03 arduino: reworked config screen, works!
    [picostepseq.ino, sequencer.h]
2023-06-19 add midi channel to picostepseq circuitpython
2023-06-19 update readme about arduino verison
2023-08-16 fix transpose val display for macropad
    [sequencer_display_macropad.py]

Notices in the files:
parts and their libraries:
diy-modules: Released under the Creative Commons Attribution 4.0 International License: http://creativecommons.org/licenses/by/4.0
